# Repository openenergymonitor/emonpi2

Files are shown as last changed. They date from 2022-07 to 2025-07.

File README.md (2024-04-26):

# emonPi v2

The emonPi2 is an energy monitor that can monitor up to 6 AC circuits using CT sensors and the OpenEnergyMonitor emonVs voltage sensing unit. It consists of a measurement board that sits on top of a RaspberryPi. The measurement board features the Microchip AVR128DB348 microcontroller - responsible for sampling the current and voltage waveforms and calculating the power and energy values. The RaspberryPi provides full local data logging and visualisation capability. The emonPi2 can also be used as a basestation to receive data from other 433Mhz radio nodes.

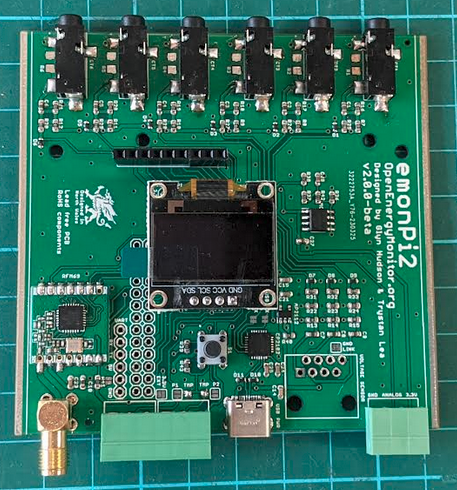
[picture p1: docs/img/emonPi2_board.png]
board


**Features**

- 6 CT sensor inputs (333mV voltage output CT's)
- RJ45: 1-3 phase voltage input
- Pulse and temperature sensing input
- Micro: AVR128DB48
- MCP1501 Precision reference
- RFM69CW radio
- USB-C
- I2C 128x64 SSD1306 Display
- RTC I2C Breakout
- Optional on-board UART

### [Hardware schematic and board files](hardware)

### [Firmware](firmware)

### Community & Support

- [OpenEnergyMonitor Forums](https://community.openenergymonitor.org)

OpenEnergyMonitor Shop Support: support@openenergymonitor.zendesk.com

### License

- The hardware designs (schematics and CAD files) are licensed under a Creative Commons Attribution-ShareAlike 3.0 Unported License.
- The firmware is released under the GNU GPL V3 license The documentation is subject to GNU Free Documentation License
- The hardware designs follow the terms of the OSHW (Open-source hardware) Statement of Principles 1.0.

### Disclaimer

```
OUR PRODUCTS AND ASSEMBLY KITS MAY BE USED BY EXPERIENCED, SKILLED USERS, AT THEIR OWN RISK. TO THE FULLEST EXTENT PERMISSIBLE BY THE APPLICABLE LAW, WE HEREBY DISCLAIM ANY AND ALL RESPONSIBILITY, RISK, LIABILITY AND DAMAGES ARISING OUT OF DEATH OR PERSONAL INJURY RESULTING FROM ASSEMBLY OR OPERATION OF OUR PRODUCTS.

Your safety is your own responsibility, including proper use of equipment and safety gear, and determining whether you have adequate skill and experience. OpenEnergyMonitor and Megni registered partnership disclaims all responsibility for any resulting damage, injury, or expense. It is your responsibility to make sure that your activities comply with applicable laws, including copyright. Always check the webpage associated with each unit before you get started. There may be important updates or corrections. All use of the instructions, kits, projects and suggestions given both by megni.co.uk, openenergymonitor.org and shop.openenergymonitor.org are to be used at your own risk. The technology (hardware , firmware and software) are constantly changing, documentation (including build guide and instructions) may not be complete or correct.

If you feel uncomfortable with assembling or using any part of the system, return it to us for a full refund.
```

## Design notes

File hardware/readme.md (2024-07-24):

# emonPi2 - Hardware

## Change Log 

### V2.0.0

First release 

### V2.0.1

**manufactured in April 2023**

- DFM tweaks 
- Fix pad sizes 
- Change USB-C connector footprint and enable duel orientation data connections 

The emonPi2 hardware schematics and board files have been developed using Eagle (now Autodesk). A free version is available to download here: https://www.autodesk.co.uk/products/eagle/free-download.

Alternatively it is also possible to open these board designs using KiKad which is open source.

**Schematic:**

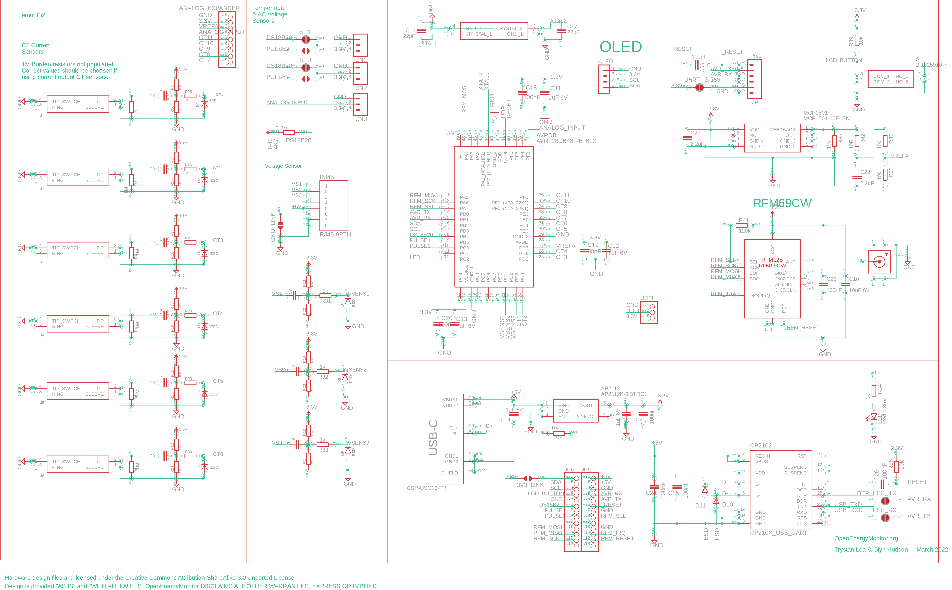
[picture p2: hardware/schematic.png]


**Board design:**

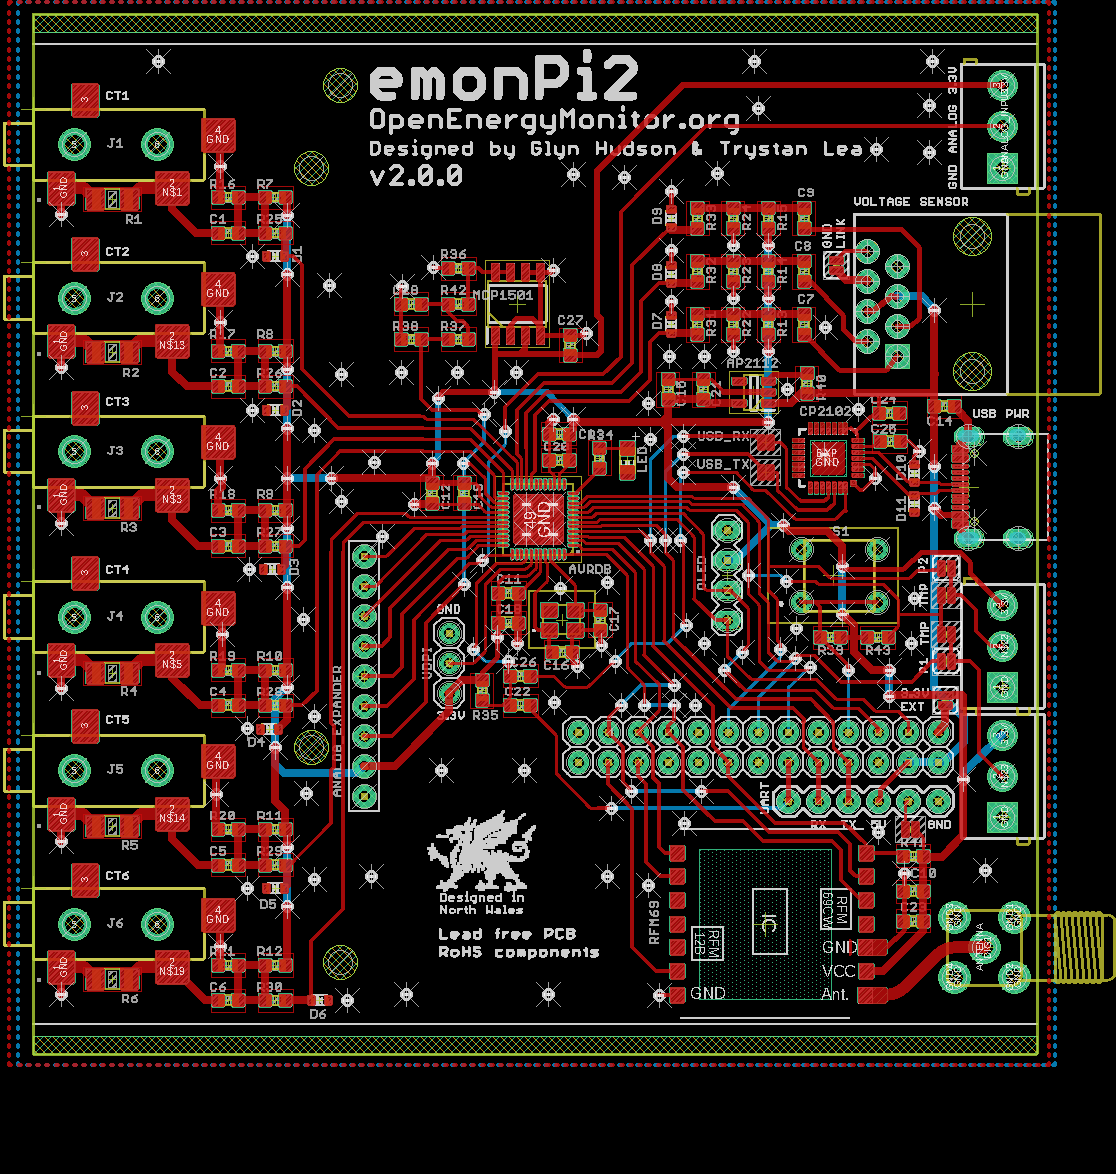
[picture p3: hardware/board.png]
board


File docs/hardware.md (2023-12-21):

---
github_url: "https://github.com/openenergymonitor/emontx4/blob/main/docs/hardware.md"
---

# Hardware

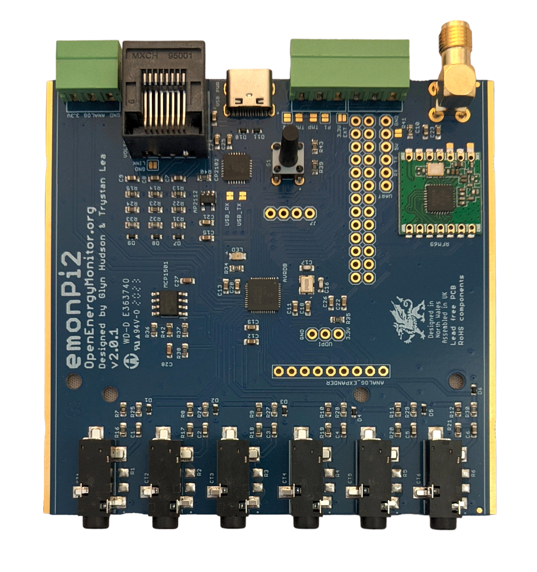
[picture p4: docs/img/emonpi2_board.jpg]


## Schematic

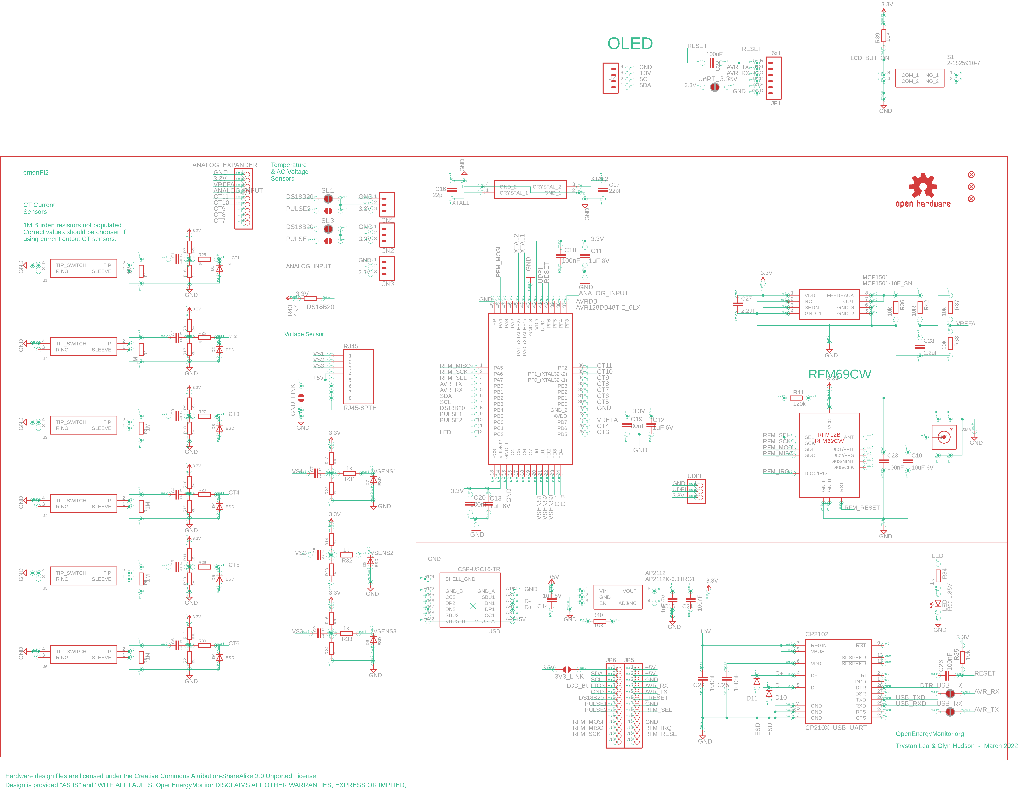
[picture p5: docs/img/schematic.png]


## Board layout

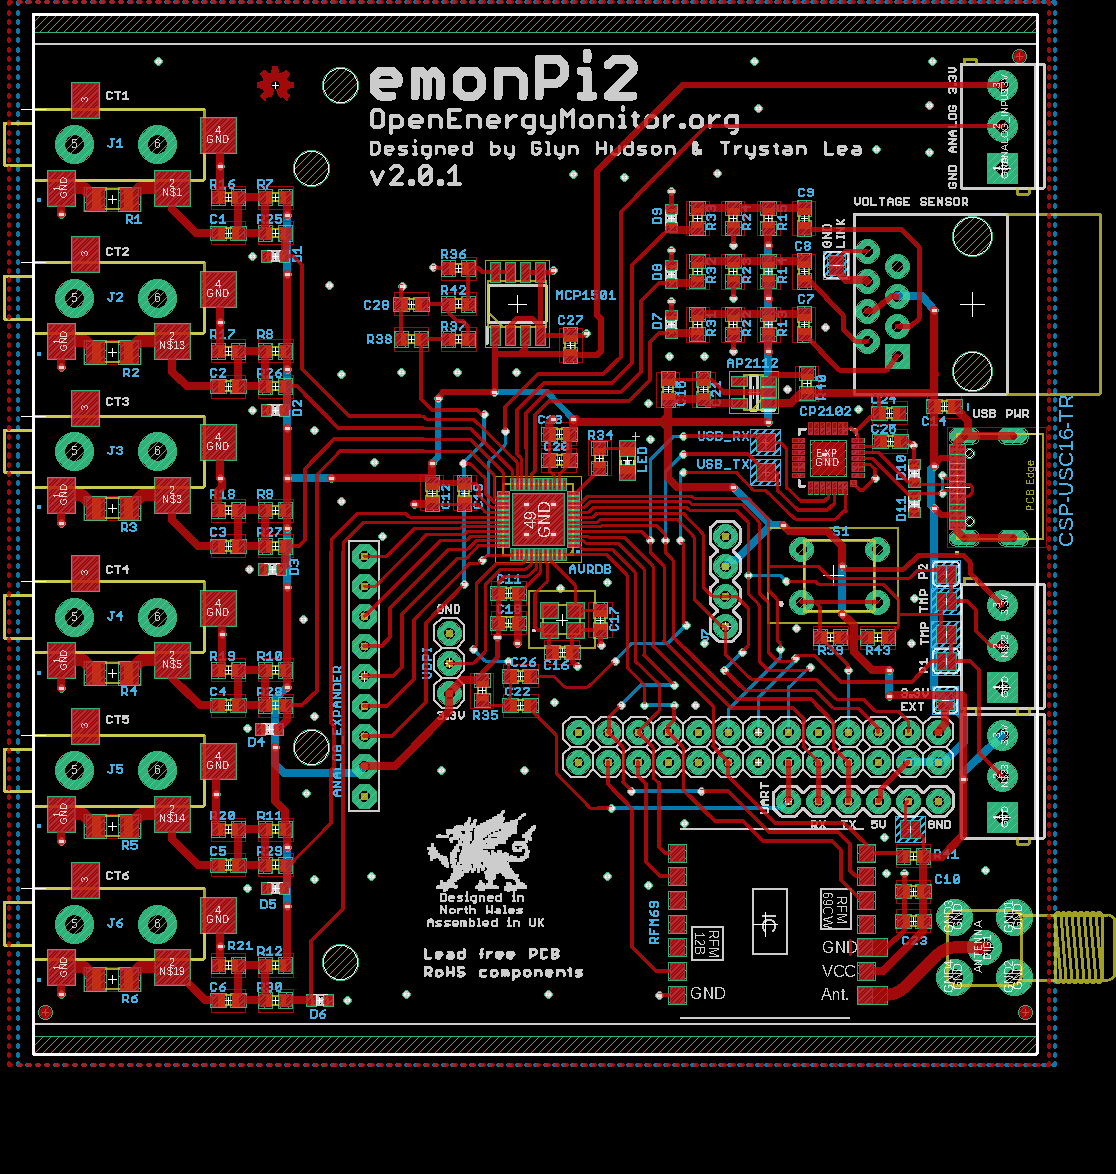
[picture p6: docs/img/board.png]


## Voltage sensor pinout

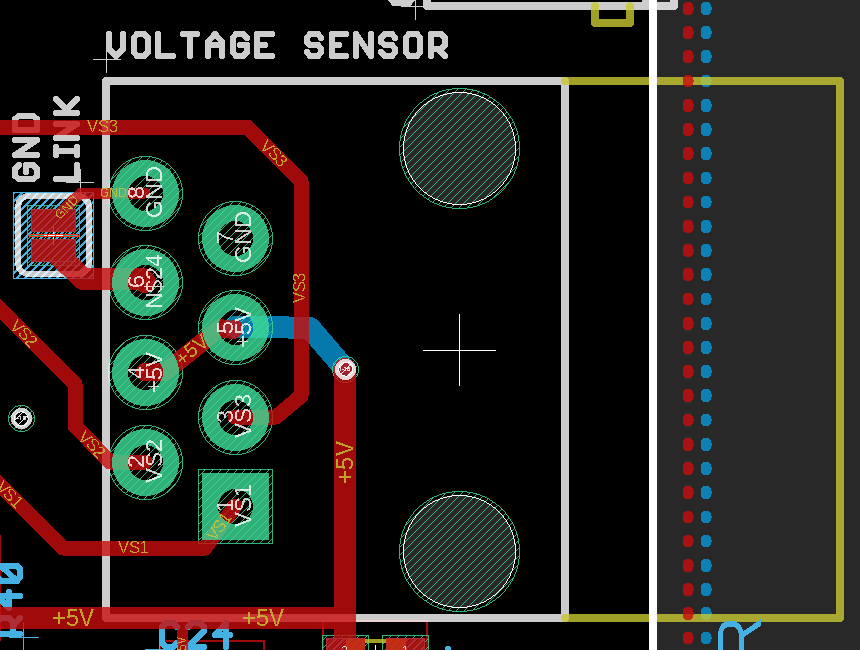
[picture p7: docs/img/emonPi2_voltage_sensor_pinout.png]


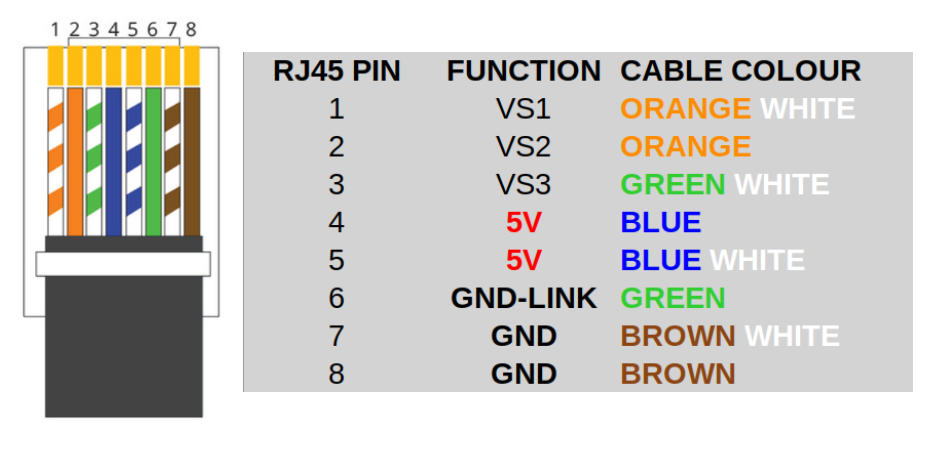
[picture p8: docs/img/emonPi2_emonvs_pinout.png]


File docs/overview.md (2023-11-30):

---
github_url: "https://github.com/openenergymonitor/emonpi2/blob/main/docs/overview.md"
---

# Overview

The emonPi2 builds directly on recent emonTx4 development, sharing a mostly identical PCB design. It provides the same 6x clip-on CT current sensor input functionality but with the RaspberryPi integrated in a single enclosure.

Like the emonTx4, the emonPi2 uses the same focus on higher accuracy, more CT channels, precision voltage sensing and the new microcontroller core. When combined with the emonVS voltage sensor and a selection of CT sensors, it provides an end-to-end electricity monitoring solution perfect for monitoring home consumption, solar generation, EV charging, heat pumps, battery storage among other applications.

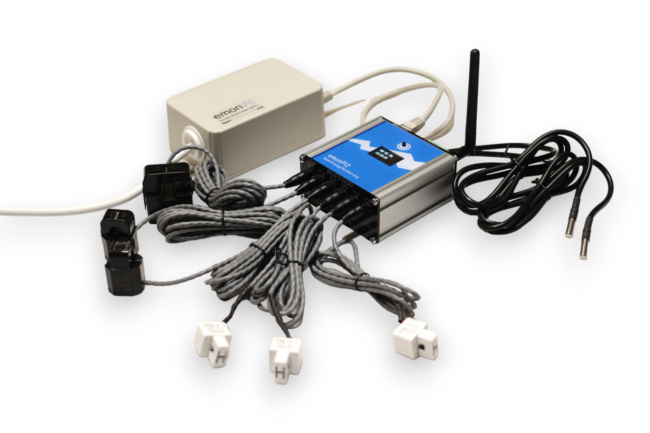
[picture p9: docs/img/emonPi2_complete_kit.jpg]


## Key features

- 6x clip-on CT current sensor inputs (suitable for a range of 333mV voltage output CT sensors).
- emonVs precision voltage sensor input.
- Full Real/Active power measurement & continuous sampling.
- Cumulative energy persisted on reboot.
- Both single and 3 phase support.
- 3 pluggable terminal block inputs for DS18B20 temperature sensing, pulse counting or an analogue voltage input.
- On-board USB to UART converter for easier programming and serial output.
- 433 MHz radio transceiver
- Standard RaspberryPi GPIO header connection for direct connection to a RaspberryPi
- Wall-mount aluminium enclosure

## Technical spec

- Microcontroller: [Microchip AVR128DB48](https://www.microchip.com/en-us/products/microcontrollers-and-microprocessors/8-bit-mcus/avr-mcus/avr-db)
- Arduino core support [DxCore by SpenceKonde](https://github.com/SpenceKonde/DxCore)
- ADC Resolution: 12-bit
- Precision voltage reference: [MCP1502](https://www.microchip.com/en-us/product/MCP1502)
- On board USB to UART converter: CP2102
- RFM69cw 433 MHz radio

## Accuracy

The emonPi2 includes the same accuracy improvements included in the emonTx4. The largest source of improvement comes from: a higher accuracy voltage sensor, higher accuracy CT current sensors and a wider range of CT sensors with current ratings that can better suit the load being monitored (making sure the analog-to-digital range of the microcontroller is being put to full use).

The key sensor and component tolerances are now:

- CT Sensors: ±0.5%
- EmonVs voltage sensor: ±0.5%
- Analog voltage reference ±0.2%
- Combined: ±1.2%

We have also upgraded the microcontroller from the ATmega328 to and AVR128DB48. The main improvement is a higher resolution ADC at 12-bits (4x the resolution of the ATmega328) alongside the capability to monitor more channels.

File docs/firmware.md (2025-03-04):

---
github_url: "https://github.com/openenergymonitor/emonpi2/blob/main/docs/firmware.md"
---

# Firmware

**Updated: 14th May 2024**<br>

There are currently 5 pre-compiled firmware options for the emonPi2 available via both the Emoncms firmware upload tool and the command line [emonupload.py](https://github.com/openenergymonitor/emonupload) firmware tool. 

**To choose the right firmware, there are 2 main questions:**

1. Is the application 1-phase, 3-phase (4-wire) or current only?<br>

2. Are you using a 6 channel expander for a total of 12 CT channels?<br>

*Note: Temperature sensing is handled by the RaspberryPi separately and so is not limited by firmware choice. The RFM69 radio transceiver is also handled by the RaspberryPi directly.*

Select the right firmware from the list that matches the requirements of your application:

| ID | Firmware | Voltage | CTs | Pulse|
| --- | --- | --- | --- | --- |
| 1 | emonPi2_DB_6CT_1phase | 1-ph | 6 | 1* |
| 2 | emonPi2_DB_6CT_3phase | 3-ph | 6 | 1* |
| 3 | emonPi2_DB_12CT_1phase | 1-ph | 12 | 3* |
| 4 | emonPi2_DB_12CT_3phase | 3-ph | 12 | 3* |
| 5 | emonPi2_CM_6CT | current only | 6 | 1 |

*The pulse sensor * denote standard firmware support for the number of pulse sensors given. Firmware modification can extend the number of pulse sensors to 3 on all emonLibDB based firmwares.*

- All firmwares include serial configuration of radio, voltage and current channel calibration values.

- **_DB:** EmonLib**DB** electricity monitoring library.<br>

- **_CM:**  EmonLib**CM** electricity monitoring library.

- **3-phase firmwares phase allocation:** follows the following pattern: 

  - CT1: phase 1
  - CT2: phase 2
  - CT3: phase 3
  - CT4: phase 1
  - CT5: phase 2
  - CT6: phase 3
  - continued for 12 CT expansion board...
  
- **3-phase (4-wire):** 3-phase support is for 3-phase, 4-wire systems only. That is systems with an L1, L2, L3 and a NEUTRAL wire. For 3-phase, 3-wire systems please contact us.

- **North American split-phase systems:** The 3-phase voltage sensor can also be used to provide voltage measurement for North American split-phase systems. A custom phase allocation will likely be required for this configuration which can be achieved by minor firmware modification.

- **Current only:** Supported by firmware 5 only, can be used with installations without an emonVs voltage sensor. These firmwares uses the older emonLibCM electricity monitoring library that has a fallback option to an assumed RMS voltage value if no AC voltage signal is detected.

- **Temperature sensing:** Is handled by the RaspberryPi separately via the emonHub software and so is not limited by firmware choice. While there is no specific limit on the number of temperature sensors that can be connected but we have only tested up to 6 temperature sensors at any one time.

- **Pulse sensing** is available on the 3 pin analog input terminal as default for all 6 CT firmwares but is disabled by default on the 12 CT firmwares as the analog input is used for CT 12. If temperature sensing is not required it is possible to configure pulse sensing on the terminal blocks connections typically used for temperature sensing.

- **Analog input:** Reading from the analog input can be enabled for all firmware variants via a `#define` compile option when compiling from source.

**Base firmwares**<br>
These are now built from a set of base firmware's common to all AVR-DB hardware variants (emonTx4, emonTx5 and emonPi2) available in the [avrdb_firmware repository](https://github.com/openenergymonitor/avrdb_firmware/)

- Firmwares 1 & 2 compiled from the `emon_DB_6CT` base firmware.
- Firmwares 3 & 4 are compiled from the `emon_DB_12CT` base firmware.
- Firmware 5 is compiled from the `emon_CM_6CT_temperature` base firmware.

---

## Updating firmware

The easiest way of updating the emonPi2 firmware is to use the firmware upload tool.

1. In your local emonPi2 web interface, navigate to: `Setup > Admin > Update > Firmware`.
2. Select serial port `ttyAMA0` and then select `emonPi2` from hardware.
3. Select firmware variant as required.



## Upload pre-compiled using EmonScripts emonupload2 tool 

On the emonPi/emonBase ensure EmonScripts is updated to latest version then run emonupload2 tool 

    cd /opt/openenergymonitor/EmonScripts
    ./emonupload2.py

Select hardware then firmware version

```
Select hardware:
  1. emonTx5
  2. emonPi2
  3. emonTx4
  4. emonPi
  5. emonTx3
  6. rfm69pi
  7. rfm12pi
  8. emonTH2
  9. JeeLink
Enter number:2

Select firmware:
1. emonPi2_DB_6CT_1phase                   2.1.0      (Standard LowPowerLabs)
2. emonPi2_DB_6CT_3phase                   2.1.0      (Standard LowPowerLabs)
3. emonPi2_DB_12CT_1phase                  1.2.0      (Standard LowPowerLabs)
4. emonPi2_DB_12CT_3phase                  1.2.0      (Standard LowPowerLabs)
5. emonPi2_CM_6CT                          1.6.0      (Standard LowPowerLabs)
Enter number:

```

emonupload2 tool can also be run on any other linux computer by cloning the EmonScripts repo then running the emonupload2.py python script. Python3 required 

    git clone https://github.com/openenergymonitor/EmonScripts

## Upload pre-compiled manually using avrdude

Alternatively to upload the same pre-compiled firmware via command line on emonPi / emonBase: 

    avrdude -C/opt/openenergymonitor/EmonScripts/update/avrdude.conf -v -pavr128db48 -carduino -D -P/dev/ttyUSB0 -b115200 -Uflash:w:emonPi2_DB_6CT_1phase_v2_1_0.ino.hex:i 

Or using different computer, ensure `avrdude.conf` has `avr128db48` entry i.e DxCore see below instructions 

    avrdude -Cavrdude.conf -v -pavr128db48 -carduino -D -P/dev/ttyUSB0 -b115200 -Uflash:w:emonPi2_DB_6CT_1phase_v2_1_0.ino.hex:i 
    
You will need avrdude installed (tested on version 6.3-2017) and the custom DxCore avrdude.conf. This can be downloaded here: [DxCore avrdude.conf](https://raw.githubusercontent.com/openenergymonitor/EmonScripts/master/update/avrdude.conf).

## How to compile and upload firmware

### Compile and Upload using PlatformIO (recommended)

Clone the `avrdb_firmware` repo 

    git clone https://github.com/openenergymonitor/avrdb_firmware
    cd avrdb_firmware/emon_DB_6CT
    
Open `emon_DB_6CT.ino` in an editor and change `#define EMONTX5` to `#define EMONPI2`. 

Change any other compile options as required e.g:

- to enable analog read uncomment `#define ENABLE_ANALOG`.
    
Install PlatformIO core then to compile and upload:

    pio run -t upload

On first run PlatformIO will download automatically all the required libraries. You can also use the PlatformIO GUI. 

### Compile and Upload using Arduino IDE 

If you don’t already have the Arduino IDE it can be downloaded from here:<br>
[https://www.arduino.cc/en/software](https://www.arduino.cc/en/software)

Once you have the IDE installed, you then need to install [Spence Konde’s DxCore](https://github.com/SpenceKonde/DxCore). This can be done by first pasting the following board manager URL in Arduino IDE > File > Preferences:

    http://drazzy.com/package_drazzy.com_index.json

Then navigating to: *Tools > Boards > Boards Manager*, Select “DxCore by Spence Konde” and click Install. 

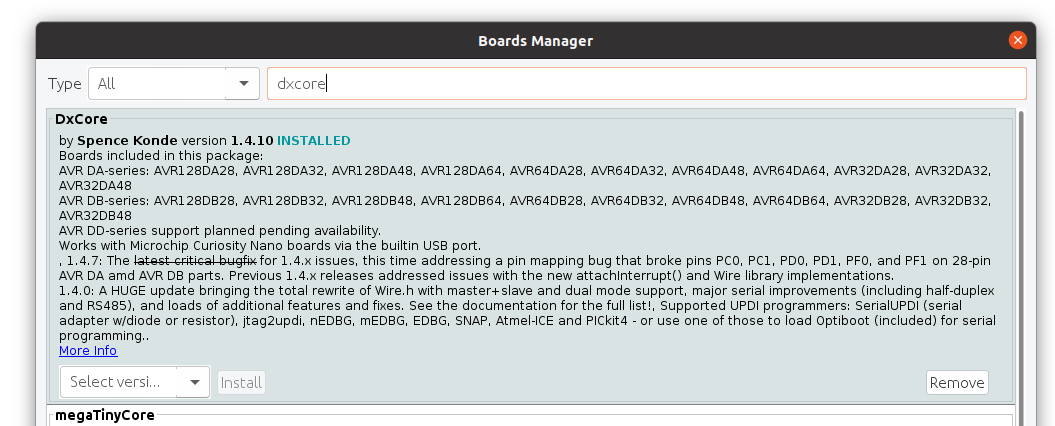
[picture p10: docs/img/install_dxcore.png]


For more information on DxCore installation see: [https://github.com/SpenceKonde/DxCore/blob/master/Installation.md](https://github.com/SpenceKonde/DxCore/blob/master/Installation.md).

**Libraries**

Locate or create your Arduino Sketchbook directory (location found in Arduino preferences). If it doesnt already exist, create a directory called libraries in the Sketchbook directory and install the following libraries:

1\. Download EmonLibCM library (avrdb branch)<br>
[https://github.com/openenergymonitor/EmonLibCM/tree/avrdb](https://github.com/openenergymonitor/EmonLibCM/tree/avrdb)

2\. Download EmonLibDB library (main branch)<br>
[https://github.com/openenergymonitor/emonLibDB](https://github.com/openenergymonitor/emonLibDB)

2\. Download emonEProm library (avrdb branch)<br>
[https://github.com/openenergymonitor/emonEProm/tree/avrdb](https://github.com/openenergymonitor/emonEProm/tree/avrdb)

3\. Download RFM69_LPL library (main branch)<br>
[https://github.com/openenergymonitor/RFM69_LPL](https://github.com/openenergymonitor/RFM69_LPL)

4\. Download RFM69_JeeLib library (avrdb branch)<br>
[https://github.com/openenergymonitor/RFM69_JeeLib/tree/avrdb](https://github.com/openenergymonitor/RFM69_JeeLib/tree/avrdb)

5\. Download DxCore SpenceKonde OneWire library:<br>
[https://github.com/SpenceKonde/OneWire](https://github.com/SpenceKonde/OneWire)

**Open and edit the AVR-DB firmware**

Clone the `avrdb_firmware` repo 

    git clone https://github.com/openenergymonitor/avrdb_firmware

Open the base firmware that you wish to use in the Arduino IDE e.g `emon_DB_6CT.ino`.

Change `#define EMONTX5` to `#define EMONPI2`. 

Change any other compile options as required e.g:

- to enable analog read uncomment `#define ENABLE_ANALOG`.

**Compilation settings:**

With DxCore and the libraries installed the firmware should then compile. 

Under Tools, select the following configuration options:

- Select Board "AVR DB-series (Optiboot)"
- Select Chip: AVR128DB48
- Clock Speed: 24 MHz Crystal
- Bootloader serial port: UART3: TXPB0, RXPB1

Select Board "AVR DB-series (Optiboot)"

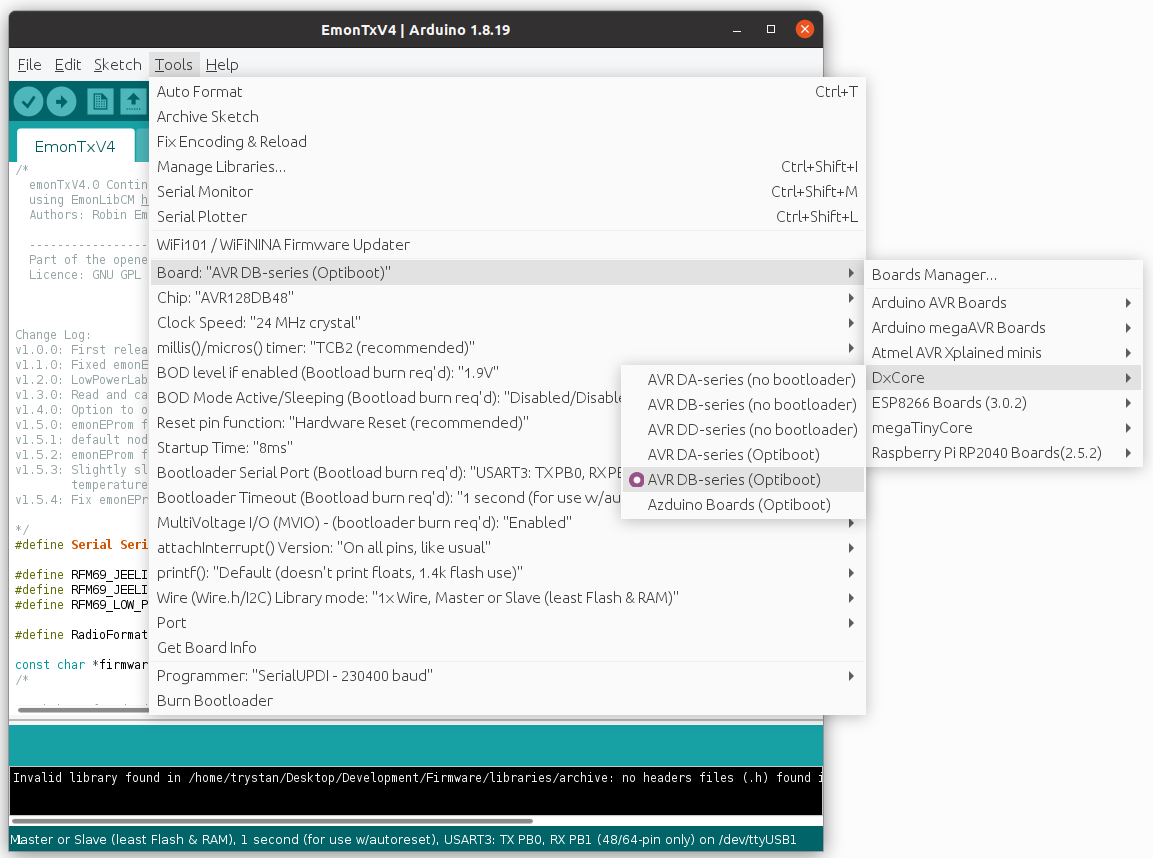
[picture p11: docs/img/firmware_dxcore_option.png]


Select Chip: AVR128DB48

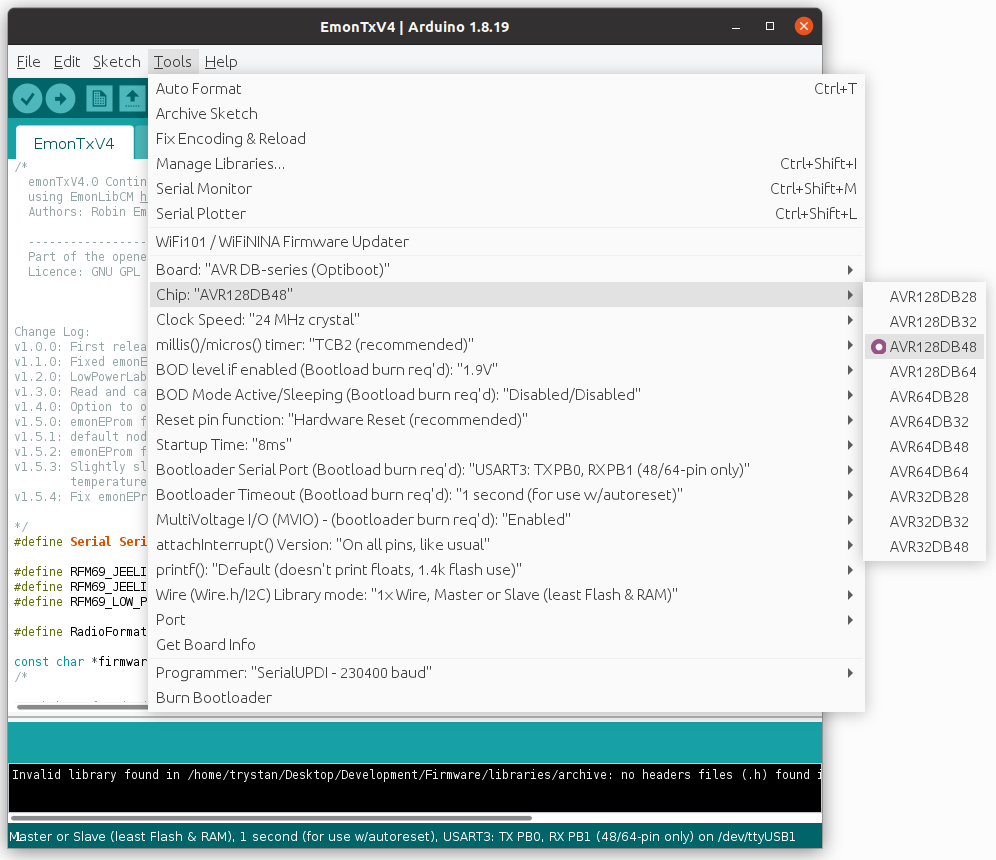
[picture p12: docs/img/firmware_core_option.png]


Bootloader serial port: UART3: TXPB0, RXPB1

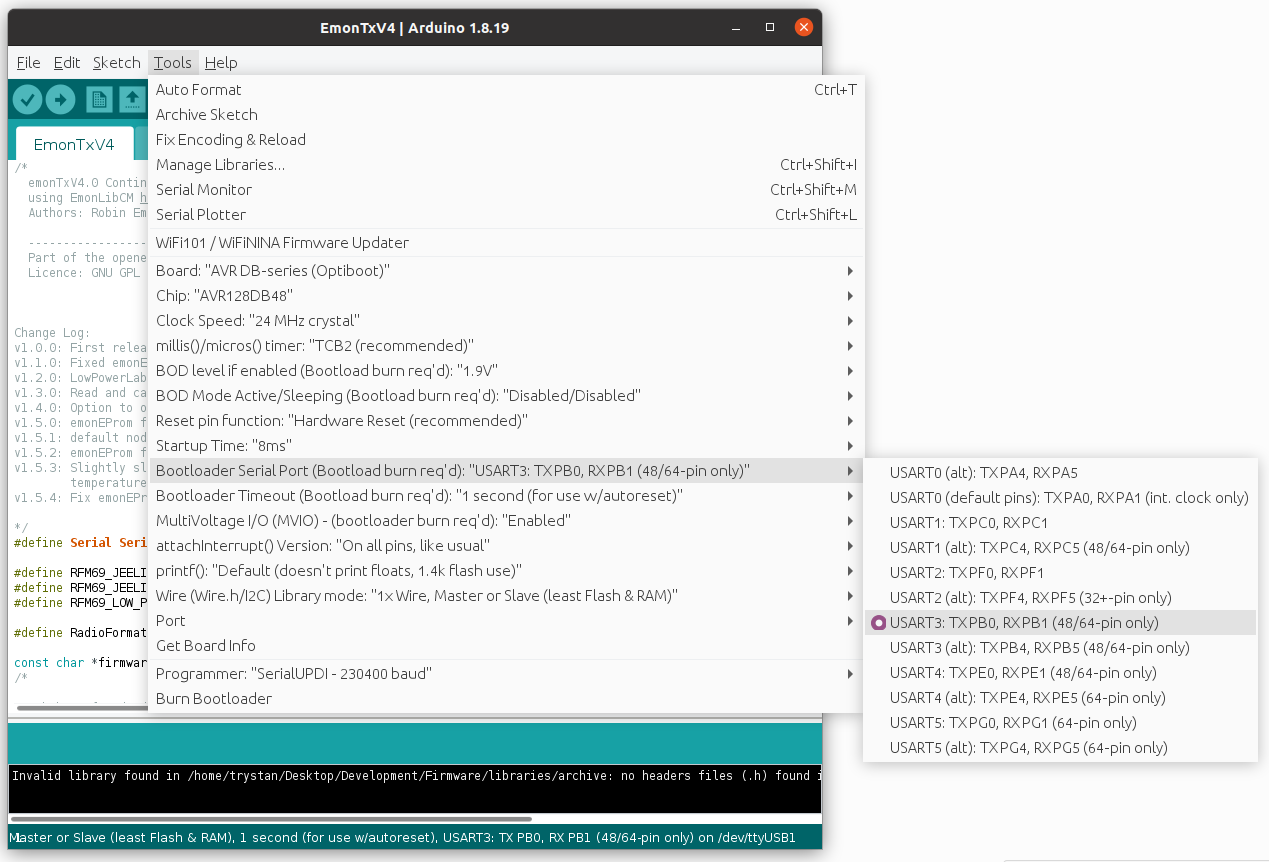
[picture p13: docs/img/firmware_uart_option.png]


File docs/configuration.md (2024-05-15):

---
github_url: "https://github.com/openenergymonitor/emonpi2/blob/main/docs/configuration.md"
---

# Configuration

CT calibration is usually pre-configured in the shop as part of the order process but can be re-configured at any point using the Serial Config tool available from the emonPi2 local Emoncms interface.

- Navigate to `Setup > Admin > Serial Config`
- Click on `Stop EmonHub` to temporarily stop the EmonHub service while we perform calibration.
- Select serial port `/dev/ttyAMA0` and click `Connect`.
- After a couple of seconds the emonPi2 will print out its current configuration which will populate the interface (if it does not do this type `l` and click `Send` to reload the calibration details from the emonPi2 measurement board).
- Adjust the  CT rating to match the CT sensor that you have installed on each channel.
- Click on `Save Changes` to ensure that the new configuration is recorded such that it persists when you power cycle the board.
- When finished, click on `Stop Serial` to disconnect the serial configuration tool and then `Start EmonHub` to restart the EmonHub service.

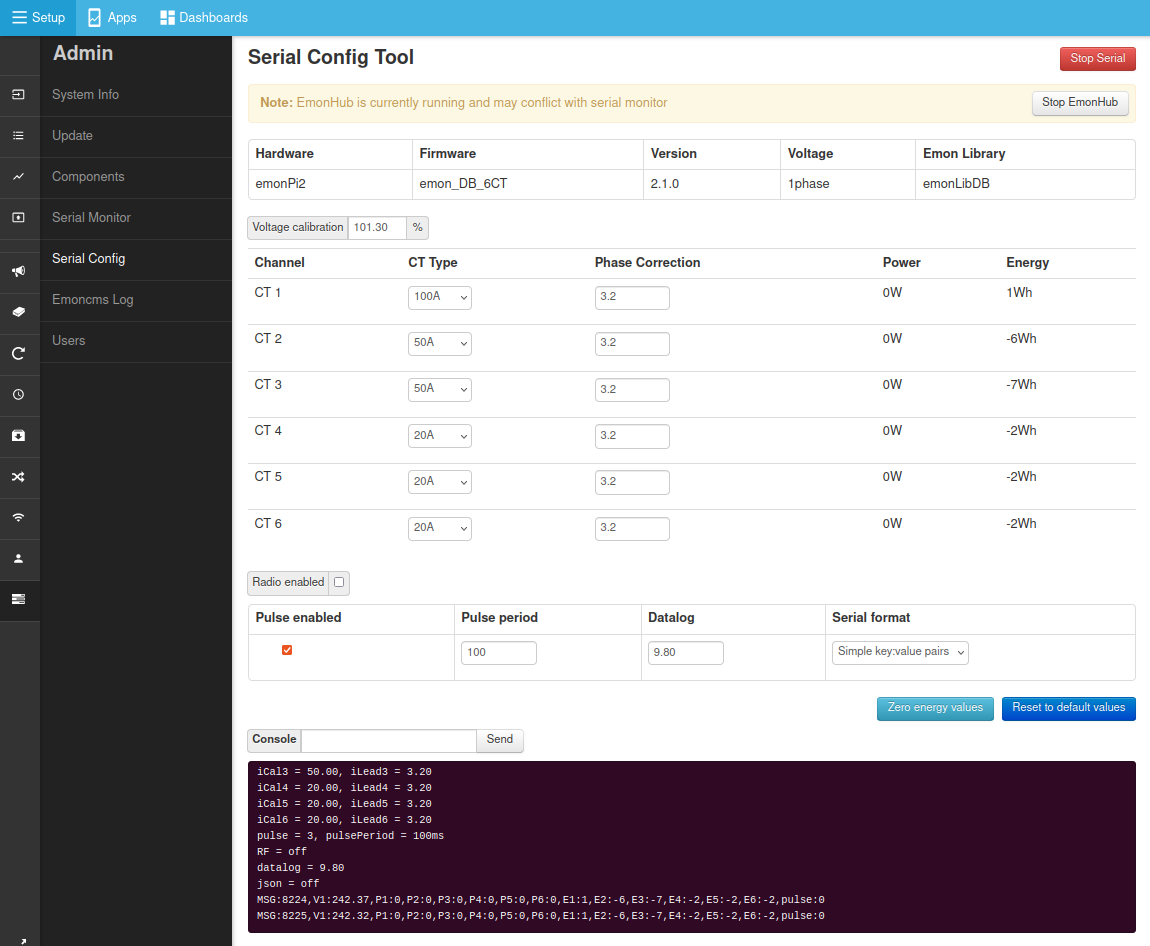
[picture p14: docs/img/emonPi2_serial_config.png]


## Directly via serial

Alternatively it's possible to configure the emonPi2 directly via serial using the arduino serial monitor or other similar tool. 
The following details the available commands and their function.

Available commands:

- **l** list the settings
- **r** restore sketch defaults
- **s** save settings to EEPROM
- **v** show firmware version
- **z** zero energy values
- **x** exit, lock and continue
- **?** show this text again
- **d\<xx.x\>** a floating point number for the datalogging period
- **c\<n\>** n = 0 for OFF, n = 1 for ON, enable current & power factor values to serial output for calibration.
- **f\<xx\>** the line frequency in Hz: normally either 50 or 60
- **k\<x\> \<yy.y\> \<zz.z\>**
  - Calibrate an analogue input channel:
  - x = a single numeral: 0 = voltage calibration, 1 = ct1 calibration, 2 = ct2 calibration, etc
  - yy.y = a floating point number for the voltage/current calibration constant
  - zz.z = a floating point number for the phase calibration for this c.t. (z is not needed, or ignored if supplied, when x = 0)
  - e.g. k0 101.3
  - k1 20.0 3.20
- **m\<x\> \<yy\>** meter pulse counting: 
  - x = 0 for OFF, x = 1 for ON
  - yy = an integer for the pulse minimum period in ms. (y is not needed, or ignored when x = 0)

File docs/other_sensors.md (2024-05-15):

---
github_url: "https://github.com/openenergymonitor/emontx4/blob/main/docs/other_sensors.md"
---

# Other sensors

## Temperature sensing

The emonPi2 supports temperature sensing via [DS18B20 temperature sensors](../electricity-monitoring/temperature/DS18B20-temperature-sensing.md). These are small temperature sensors with a 12-bit ADC and a digital output all in the sensor itself. Communication is over a one-wire bus and requires little in the way of additional components. The sensors have a quoted accuracy of ±0.5°C in the range -10°C to +85°C.

```{tip}
<b>Temperature sensing is handled by the RaspberryPi directly</b> rather than the measurement board microcontroller. This removes the hard limit on the number of temperature sensors that can be connected to the bus and allows sensor addresses to appear directly on the Emoncms inputs page. It also improves the accuracy of the electricity monitoring as the measurement board is freed up to focus soley on this task.

We have tested up to 6 temperature sensors connected at once, the one-wire bus should however support more than this. There is a useful discussion on how many sensors can be supported on a single RaspberryPi GPIO input [here](https://raspberrypi.stackexchange.com/questions/23701/what-is-the-maximum-number-of-ds18b20-probes-that-can-attached-to-one-input-port).
```

DS18B20 temperature sensors are connected via the labelled pluggable terminal blocks (multiple sensors can be connected to each temperature input, e.g using a 6x sensor breakout board). *Please note that temperature sensing is not broken out on the RJ45 connector which is for voltage sensing and power only.* 

**Pluggable terminal block connections are:**<br>
GND (black), DATA (yellow), 3.3V (red), left to right, repeated for each of the three blocks:

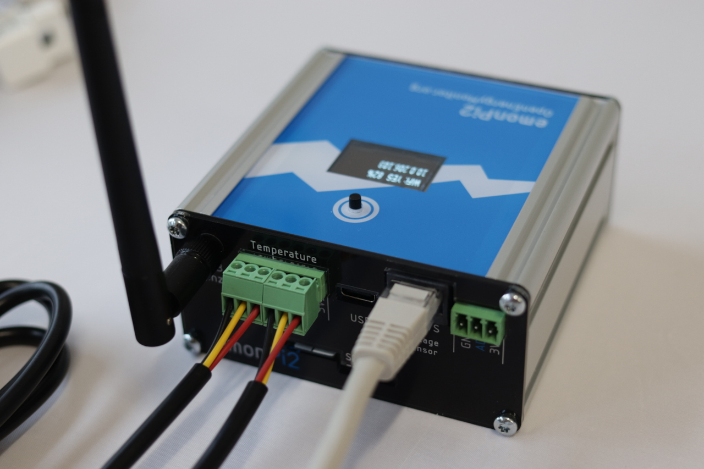
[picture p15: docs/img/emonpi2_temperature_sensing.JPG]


The function of the emonPi2 terminal blocks can be changed with small solder-jumpers just above the terminals on the measurement board PCB. The default configuration is 2x temperature sensor inputs, one on each terminal block. Notice the bridged solder jumpers labelled 'TMP' in the picture below: 

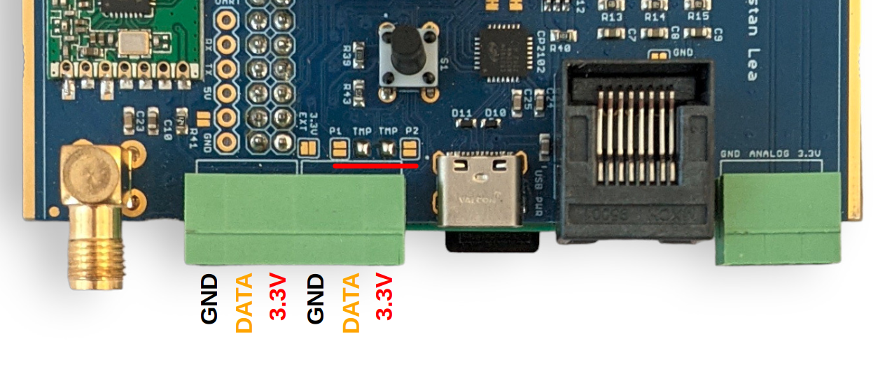
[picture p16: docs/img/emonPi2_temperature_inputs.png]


The DS18B20 input is connected to GPIO17 on the RaspberryPi via the GPIO connection header. *It is also connected to digital PIN_PB4 on the AVR128DB48 microcontroller for use in transmitter mode as part of an emonTx5.

## Pulse counting

**Update 14th May 2024:** When running the latest emonPi2 single phase or three phase firmware, pulse counting is attached to the analog input as standard which leaves the other terminals for easier connection of multiple temperature sensors.

The OpenEnergyMonitor pulse counter can connected like this:

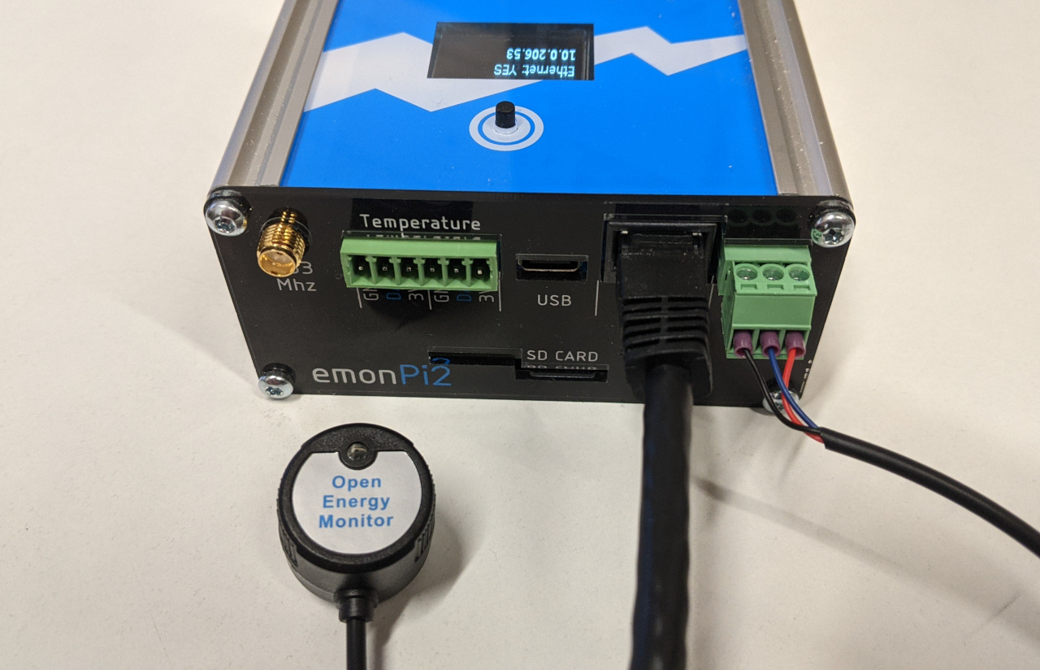
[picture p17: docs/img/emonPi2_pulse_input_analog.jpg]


This pulse input will appear alongside the energy monitoring data from the emonPi2 on the emoncms inputs page. Note that the voltage sensor is required for this firmware to work.

---

**Pulse sensing using the terminals labelled 'temperature'**:

While the left hand side terminal block inputs are configured for temperature sensing as standard, it's possible to change the function of the 'Data' pin on each of the terminal block inputs. The following picture shows both inputs configured for pulse counting rather than temperature sensing, notice the moved solder pad bridges:

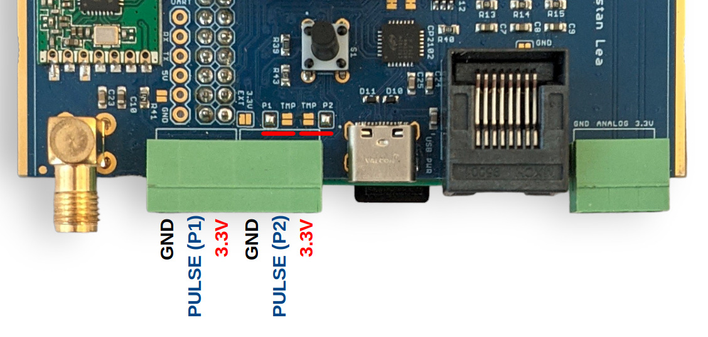
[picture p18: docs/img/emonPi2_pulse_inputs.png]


```{note}
<b>T1</b> can be either a pulse input (<b>Pi GPIO27 PIN13</b> or AVR-DB PIN_PB5) or temperature sensing (<b>Pi GPIO17</b> or AVR-DB PIN_PB4)

<b>T2</b> can be either a pulse input (<b>Pi GPIO22 pin-15</b> or AVR-DB PIN_PC0) or temperature sensing (<b>Pi GPIO17</b> or AVR-DB PIN_PB4)
```

It is easy to increase the number of pulse inputs when temperature sensing is not required. Simply select the P1 and P2 solder bridges above and add the following emonhub.conf interfacer configuration. This will enable direct readings from the applicable pulse inputs on the Pi, bypassing the AVR-DB microcontroller:

```
[[pulse1]]
    Type = EmonHubPulseCounterInterfacer
    [[[init_settings]]]
        pulse_pin = 13
        # bouncetime = 2
        # rate_limit = 2
    [[[runtimesettings]]]
        pubchannels = ToEmonCMS,
        nodeoffset = 1

[[pulse2]]
    Type = EmonHubPulseCounterInterfacer
    [[[init_settings]]]
        pulse_pin = 15
        # bouncetime = 2
        # rate_limit = 2
    [[[runtimesettings]]]
        pubchannels = ToEmonCMS,
        nodeoffset = 2
```

On pulse detection, the pulse inputs will appear on the Emoncms inputs page:

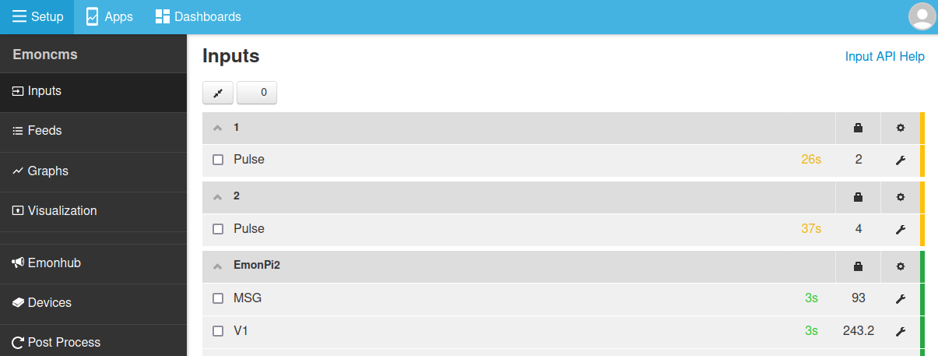
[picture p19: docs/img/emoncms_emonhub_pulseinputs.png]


---

## Analog input

It's possible to link analog input AIN19 (CT12) to right-most terminal block as shown here. An example application is measuring flow rate using a Sika VFS which has an analog voltage output.

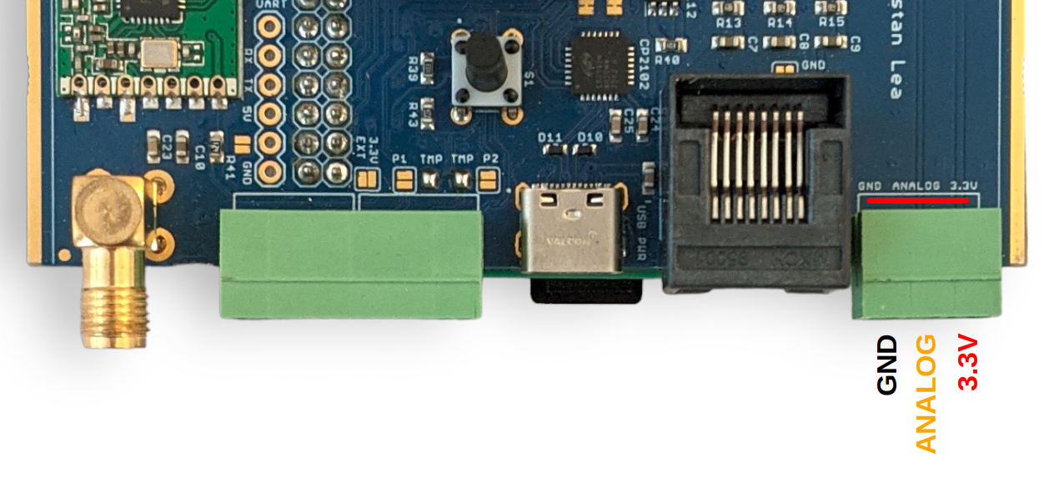
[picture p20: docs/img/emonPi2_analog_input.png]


```{warning}
The analog input voltage must be in the range **0 - 1.024V**. This ADC is configured for this range in order to suit the 333mV CT sensors. This analog input can not be used when using the emonPi2 with the C.T Extender board.
```

Using the analog input requires compiling and uploading custom configuration of the emonPi2 firmware. Start by setting up the Arduino IDE environment following the [firmware guide](firmware.md).

Open the base firmware `emon_DB_6CT` from the [avrdb_firmware](https://github.com/openenergymonitor/avrdb_firmware) firmware repository.

1\. Make sure to select EMONPI2 as the hardware variant:

```
// 1. Set hardware variant
// Options: EMONTX4, EMONTX5, EMONPI2
#define EMONPI2
```

2\. Uncomment the line `#define ENABLE_ANALOG`:

```
// 6. Enable analog reading (disabled by default)
// #define ENABLE_ANALOG
```

3\. Select 1phase or 3phase as required:

```
// 3. Set number of voltage channels (1 for single phase, 3 for three phase)
#define NUM_V_CHANNELS 1
```

4\. Compile and upload the firmware to the emonPi2

With this firmware loaded the analog input will appear in the input list.

The following set of screenshots gives an example of configuring this analog input for use in reading the flow rate from a Sika VFS flow sensor. The flow rate is then used together with measurement of flow and return temperature to calculate heat.

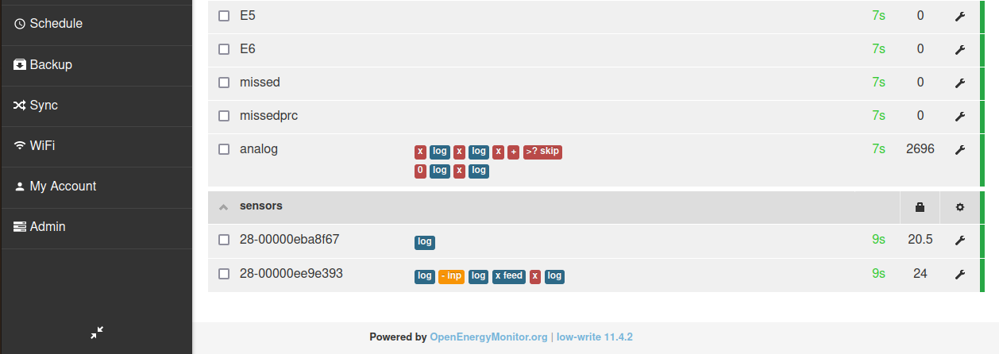
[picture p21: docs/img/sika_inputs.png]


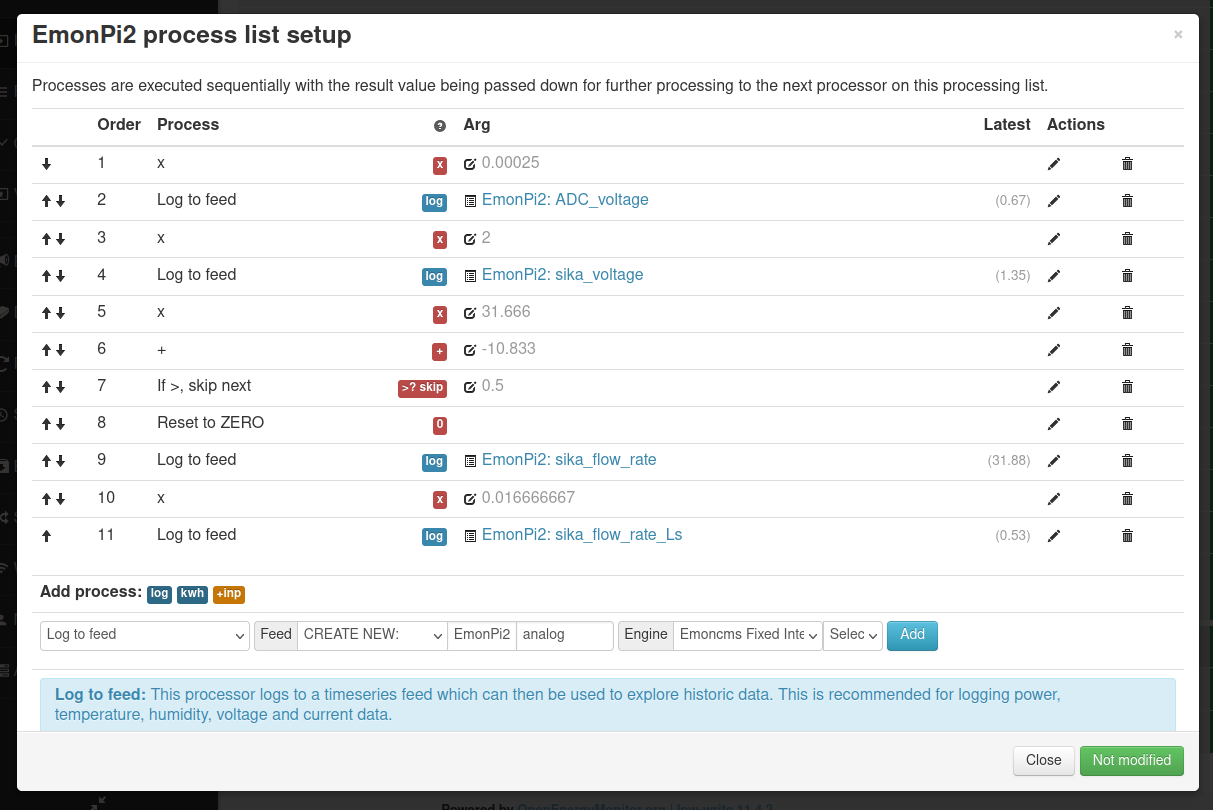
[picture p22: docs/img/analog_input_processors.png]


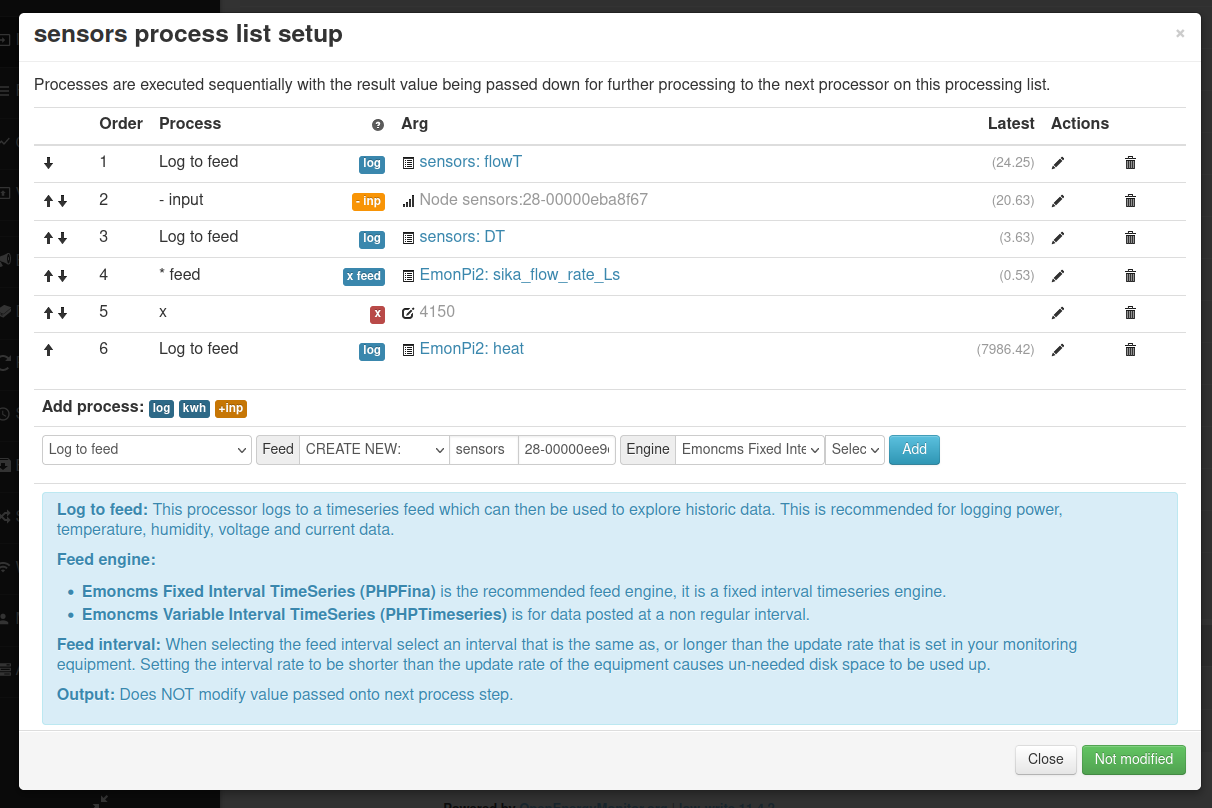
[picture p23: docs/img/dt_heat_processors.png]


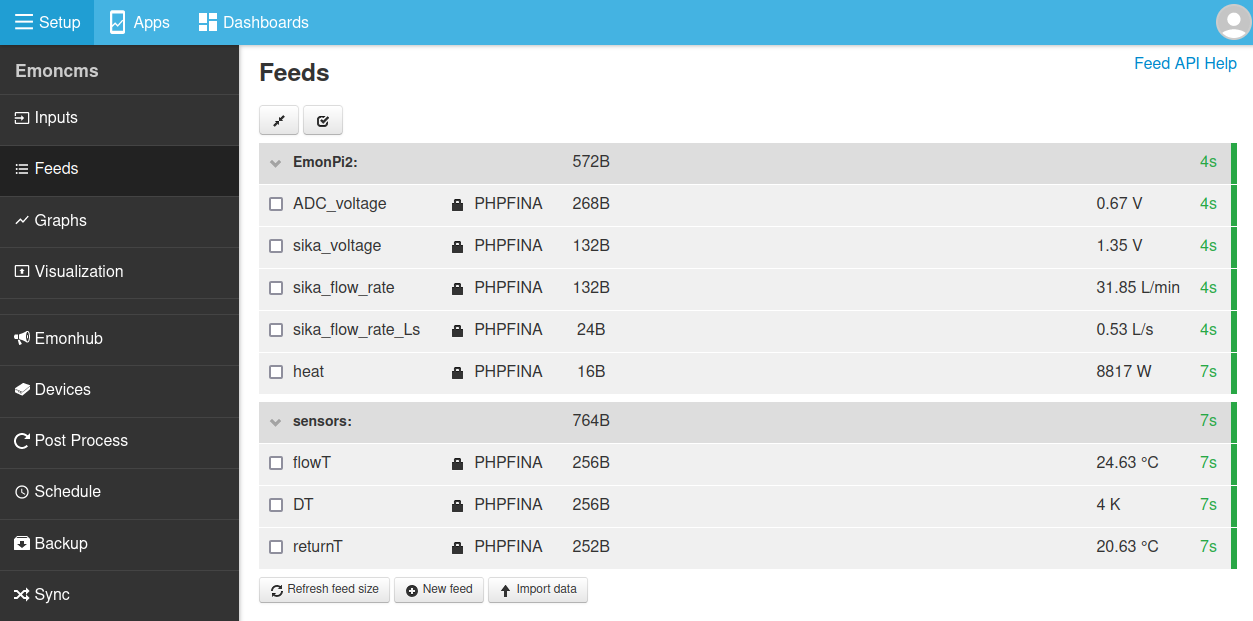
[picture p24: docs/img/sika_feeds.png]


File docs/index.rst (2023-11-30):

emonPi2 User Guide
==================

.. toctree::
   :maxdepth: 2
   
   overview.md
   Install Guide <install.md>
   configuration.md
   firmware.md
   hardware.md
   Temperature, Pulse & Analog <other_sensors.md>

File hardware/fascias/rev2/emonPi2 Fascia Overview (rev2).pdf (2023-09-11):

Back (92mm x 45mm)

Bottom Plate
(74mm x 85mm)

Material: Clear acrylic 2mm Red = No screen print (clear) Gray = Cut-out (hole)
White / blue = screen print

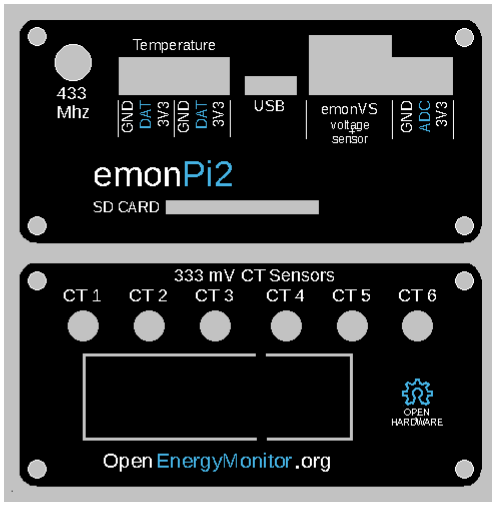
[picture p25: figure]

OpenEnergyMonitor emonPi2 rev 2 | U-Case 1 extrusion - x 85mm long (quote:130895)

Material: Black 2mm acrylic Gray = Cut-out
White / blue = screen print

Front (92mm x 45mm) Top plate (74mm x 85mm)

Material: aluminium plate
(gray) 1.9mm
TOP | FASCIAS | BOTTOM

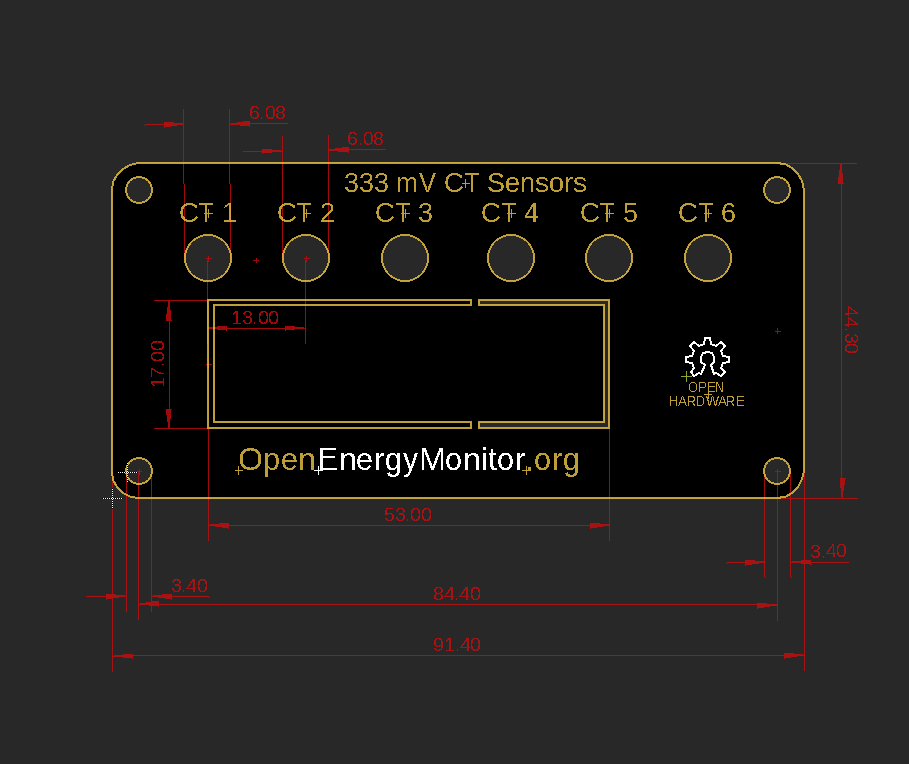
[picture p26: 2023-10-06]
hardware/fascias/rev2/dxf - emonPi2 rev3/front-dimentions.png

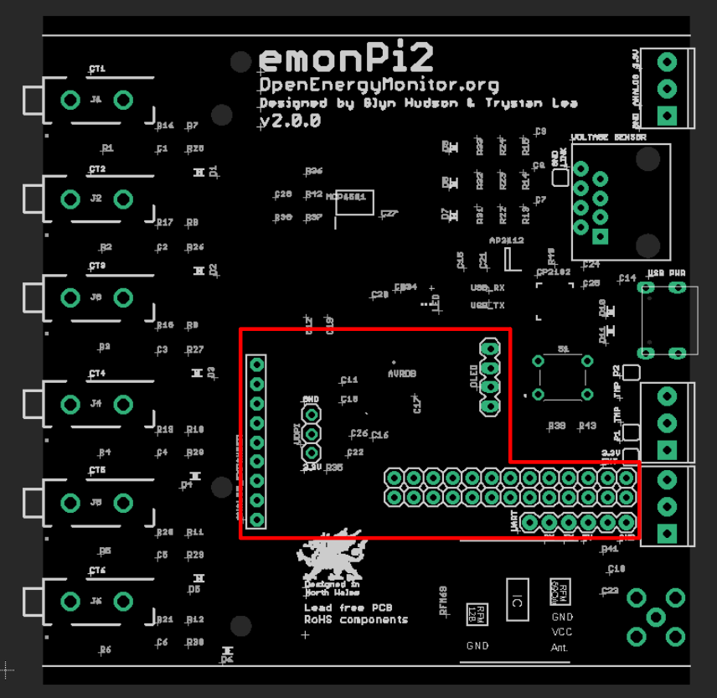
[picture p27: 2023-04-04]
hardware/hole_masking.png

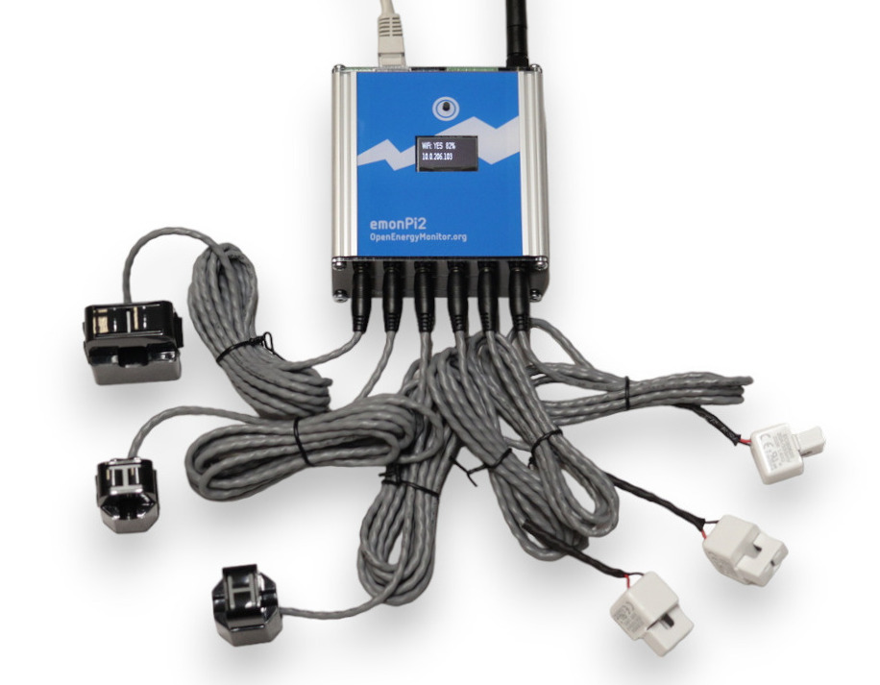
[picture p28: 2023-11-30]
docs/img/emonPi2_CTs2.jpg

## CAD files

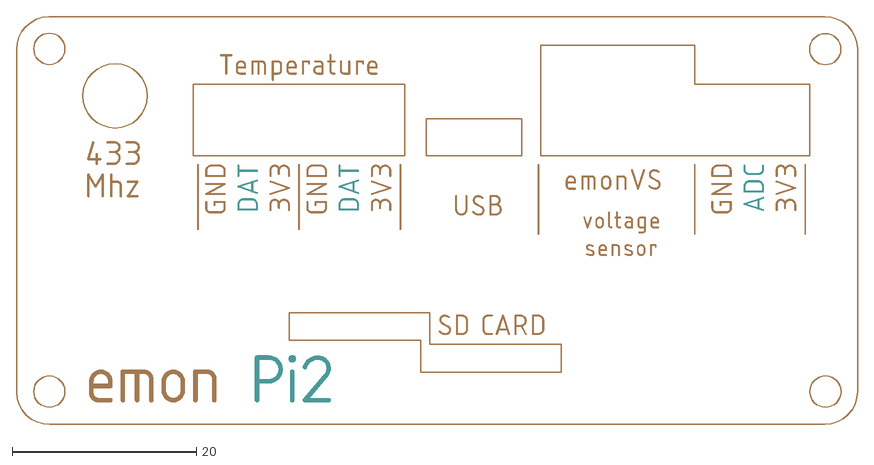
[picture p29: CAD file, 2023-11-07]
hardware/fascias/rev2/dxf - emonPi2 rev3/back.dxf
91.4 x 44.4

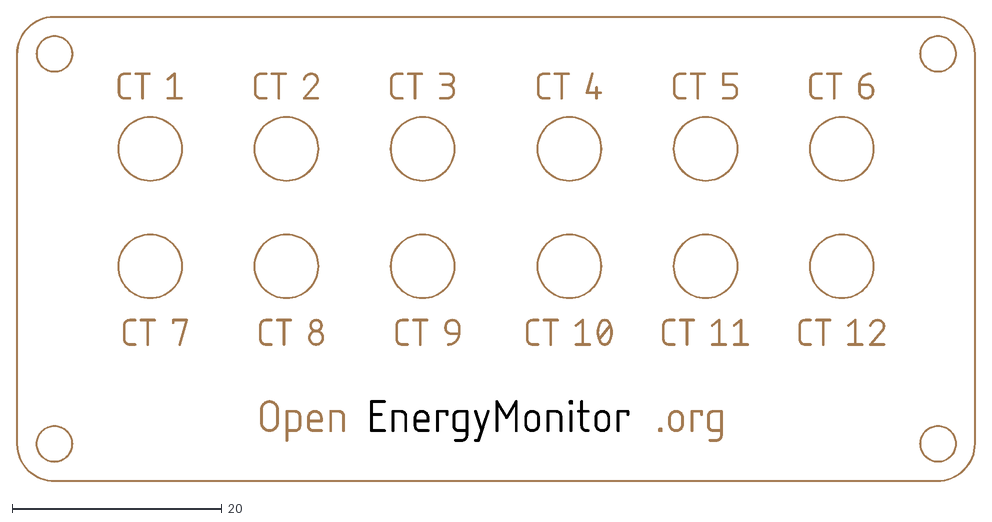
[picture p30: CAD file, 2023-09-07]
hardware/fascias/rev2/frontB.dxf
91.5 x 44.5

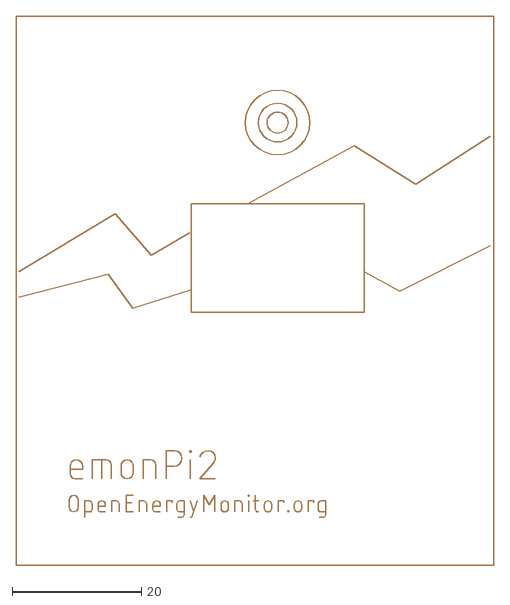
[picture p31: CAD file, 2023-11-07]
hardware/fascias/rev2/dxf - emonPi2 rev3/top.dxf
74.0 x 85.0

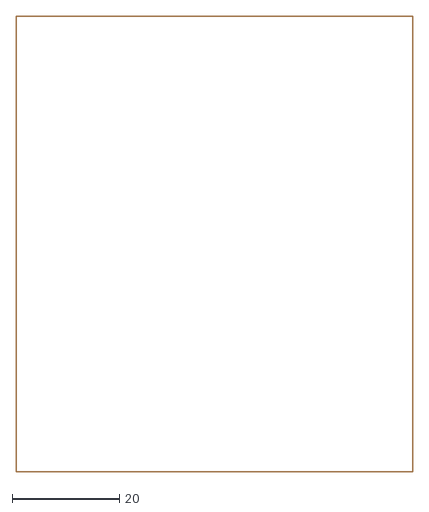
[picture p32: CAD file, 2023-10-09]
hardware/fascias/rev2/dxf - emonPi2 rev3/bottom.dxf
74.0 x 85.0

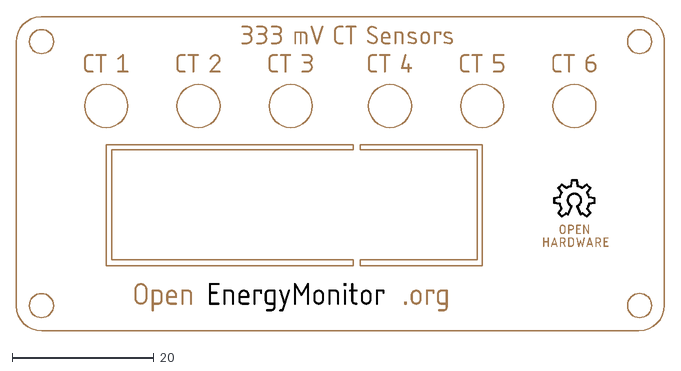
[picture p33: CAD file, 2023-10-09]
hardware/fascias/rev2/dxf - emonPi2 rev3/front.dxf
91.5 x 44.4

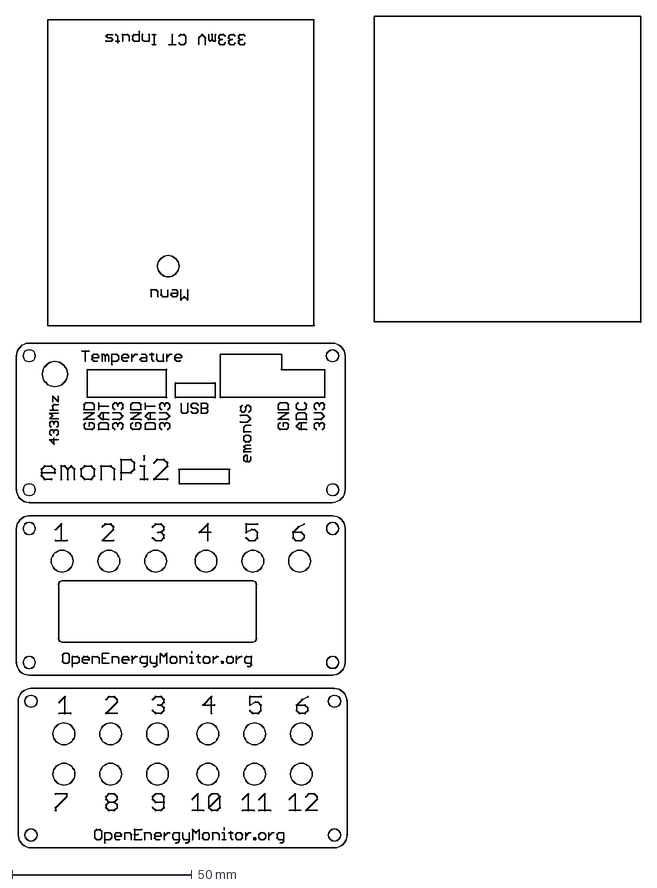
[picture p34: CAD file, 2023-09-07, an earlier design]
hardware/fascias/rev1/#fascias_v2.0.0-2mm.dxf
173.6 x 231.3 mm

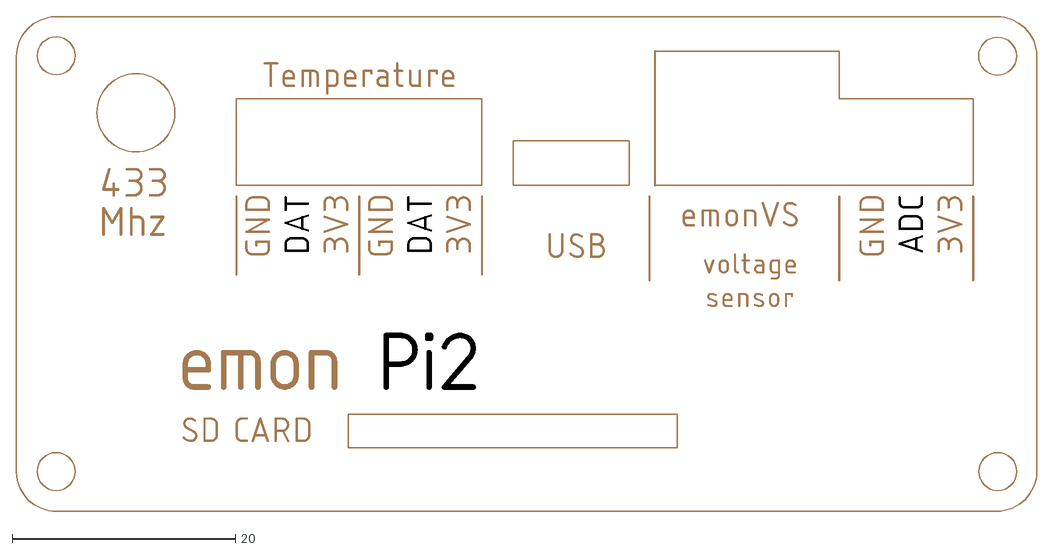
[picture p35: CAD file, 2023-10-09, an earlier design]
hardware/fascias/rev2/dxf - emonPi2 rev2/back.dxf
91.4 x 44.4

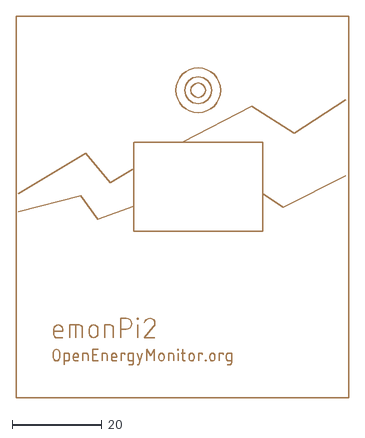
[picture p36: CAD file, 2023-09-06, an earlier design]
hardware/fascias/rev2/dxf - emonPi2 rev2/top.dxf
74.0 x 85.0

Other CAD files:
hardware/fascias/rev1/fascias_v2.0.0-2mm.dxf

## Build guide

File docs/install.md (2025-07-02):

---
github_url: "https://github.com/openenergymonitor/emonpi2/blob/main/docs/install.md"
---

# emonPi2 Install Guide

The following guide covers installation of the [emonPi2 6x input energy monitor and integrated base-station](overview.md).

<iframe width="560" height="315" src="https://www.youtube.com/embed/XAJV5zDJF_4?si=5aG4XxaeXYWK0_xQ" title="YouTube video player" frameborder="0" allow="accelerometer; autoplay; clipboard-write; encrypted-media; gyroscope; picture-in-picture; web-share" referrerpolicy="strict-origin-when-cross-origin" allowfullscreen></iframe>

**Hardware covered in this guide:**

- [emonPi2: 6 input energy monitor](overview.md)
- [emonVs: Precision voltage sensor and power supply](voltage_sensors.md)
- Up to 6 CT sensors
- RJ45 voltage sensor and power supply cable

## Quick Start

1. Clip the CT current sensors around Live OR Neutral cable of the AC circuit to be measured (not both), note CT direction K -> L (L: Load), That’s on the Line conductor, the arrow points
away from the load on the Neutral.

2. Plug the CT current sensors into emonPi2 via 3.5mm jack plugs

3. Plug emonVs RJ45 cable into emonPi2

4. Plug emonVs into mains power via a domestic wall socket

5. (optionally) If you have the RaspberryPi 4 variant of the emonPi2 a hard wired Ethernet internet/LAN connection can be connected.

6. Switch on mains socket. The display on the emonPi2 will show `emonPi2, starting..`. On the SD card side of the case the RaspberryPi 4 indicator LED should be visible through the black face plate.

7. If using Ethernet, continue with [step 5. Connecting via Ethernet](#connecting-via-ethernet). If using WiFi, continue with [step 6. Connecting via WiFi](#connecting-via-wifi).

```{admonition} Instructions for safe use
- Clip-on CT sensors are non-invasive and should not have direct contact with the AC mains. As a precaution, we recommend ensuring all cables are fully isolated prior to installing. If in doubt seek professional assistance.
- Do not expose to water or moisture
- Do not expose to temperate above rated operating limits
- Indoor use only
- Do not connect unapproved accessories
- Please contact us if you have any questions
```



---

## Extended version

A good place to start is to assess the location where you wish to install the emonPi2, identify the circuits that you wish to monitor using the clip-on CT sensors and decide how you would like to install the emonVs voltage sensor. There are a couple of example installations given below which may provide inspiration.

## 1. emonVs installation

There are two different ways of installing the [emonVs voltage sensor](https://shop.openenergymonitor.com/power-supplies/):

**Using the mains plug supplied:** If you have a convenient socket near-by this will be the easiest and quickest option.<br>

**Direct installation:** The emonVs can be hardwired by a suitably competent person into a 6A or lower circuit protection device in the fuse board (consumer unit) or a 3A fused spur. The supplied emonVs mains power cable has a cross sectional area of 1.0mm<sup>2</sup>. This can provide a tidy installation if no socket is available and helps ensure higher monitoring uptime if sockets are at risk of being unplugged for use by other appliances.

The emonVs unit can be wall mounted using the brackets on the enclosure.

If in North America, you likely want the [3-phase version of the emonVS](https://shop.openenergymonitor.com/emonvs-3-phase-no-plug/), as this will allow you to use the split phase [firmware](firmware.md). The split phase firmware enables the most accurate power measurements.

If you plan on using an [emonTx5 with your emonPi2](../emontx5/install.md), you will likely want an [emonVs RJ45 duplicator](https://shop.openenergymonitor.com/emonvs-rj45-duplicator/) to use a single emonVs with both devices.

## 2. CT sensor installation

- Current transformers (CTs) are sensors that measure alternating current (AC).

- The emonPi2 supports a wide variety of 333mV voltage output CT sensors. We stock 20A, 50A, 100A & 200A options in the OpenEnergyMonitor shop. The physical size of these CT sensors is also roughly proportional to their current rating. For highest accuracy it's a good idea to choose CT sensors that match the rating of the circuit being monitored. As an example a 20A CT should be used for 16A or 20A circuits, a 50A CT for 32A EV chargers or 100A CT for whole house monitoring (assuming a 100A rated supply).

- CT sensors need to be clipped around the Live OR Neutral cable of the AC circuit to be measured (not both). The CT sensors have an indicated direction printed on the case `K->L`, where L is the direction of the load. That’s on the Line conductor, the arrow points away from the load on the Neutral. This will ensure the correct sign (+/-) on the power readings.

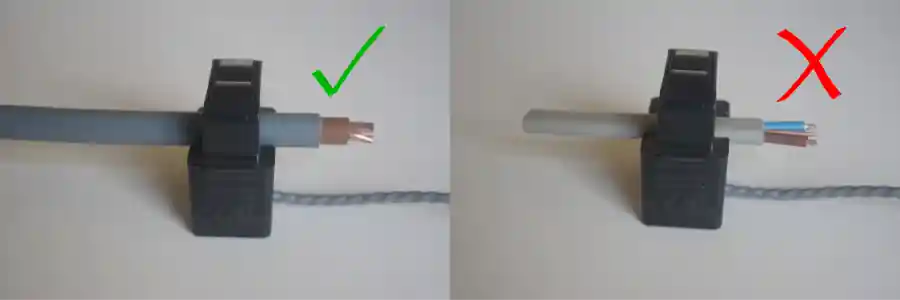
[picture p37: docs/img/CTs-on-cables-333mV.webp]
CTs on cables
  

- Take care not to compress the sensor with any sideways force as this can affect the accuracy of the measurement.

- The new range of CT sensors used with the emonPi2 are all voltage output CT sensors with integrated burden resistors and so are safe to clip on to the circuits that you wish to measure before plugging into the emonPi2 if that makes installation easier.

- Note the CT sensor used on each circuit, as well as the channel number on the emonPi2 that the CT is connected to, as this may be required to calibrate the emonPi2 if you are using non standard CT ratings. It's worth making a physical note of this on a label next to the emonPi2 for future reference.

```{note}
The emonPi2 requires voltage output CT sensors, it is not compatible with the old current output YHDC (blue) 100A CT sensors - unless appropriate burden resistors are installed.
```

```{tip} 
With 6 CT sensor cables and often more cable than you need, it's easy for an installation to look like a hive of wires! A little electrical trunking can go a long way to tidying it all up, allowing for excess cable to be looped back on itself.
```

## 3. emonPi2 Installation

- The emonPi2 can be wall mounted using the wall mounting kit supplied. Installation on it's side, with the aluminium side plates on the top and bottom can help reduce risk of things falling onto the sockets and can make for an easier installation in terms of CT sensor routing.

- Plug in the CT sensors, note which CT sensor is plugged into each input on the emonPi2 as each input needs to have the correct calibration applied.

- Connect the RJ45 cable (ethernet sized connector with 8 pins) from the emonVs voltage sensor and power supply to the RJ45 socket on the opposite side of the case to the CT sensor sockets. (If you have the RaspberryPi 4 variant of the emonPi2 the RaspberryPi Ethernet socket is on the same side as the CT sensors, avoid plugging the emonVs RJ45 cable into the Ethernet socket and vice versa).

## 4. Startup and display menu

With the emonPi2 powered up a simple `emonPi2 starting...` message will be printed on the display. The RaspberryPi is booting at this point which usually takes around 40 seconds: 

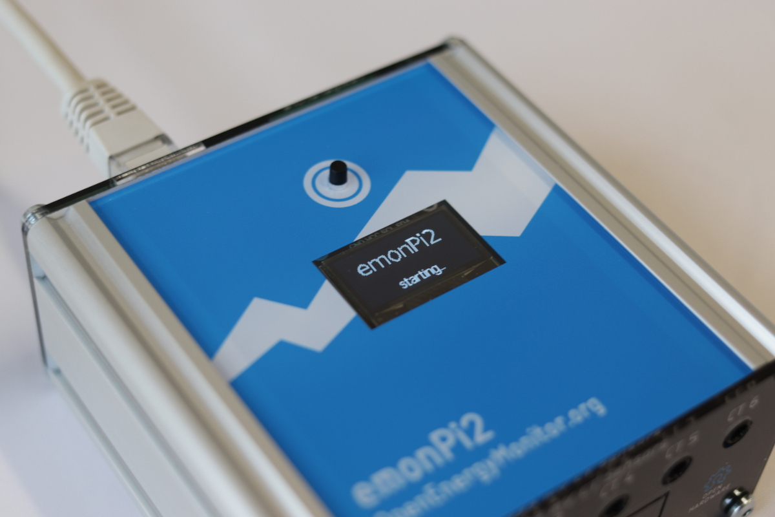
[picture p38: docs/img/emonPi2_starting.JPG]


Once booted the display will print the SD card image version and emonPi2 serial number: 

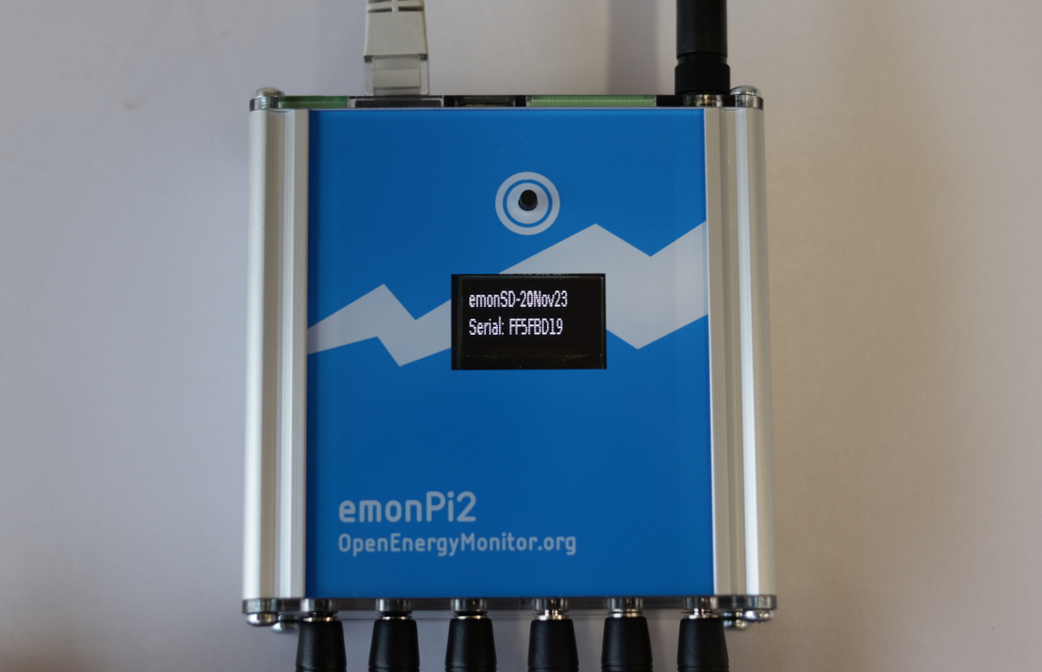
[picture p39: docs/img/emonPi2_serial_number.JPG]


Scroll through the display menu by pushing the button above the display. The menu items are:

1. emonSD image version and hardware serial number.
2. Time and date and uptime
3. Ethernet status (or if connected IP Address)
4. WiFi status (or if connected IP Address)
5. WiFi Access Point (AP) status and if enabled IP Address
6. Enable or Disable WiFi Access Point (press and hold for 5 seconds to change)
8. Enable or Disable SSH access (press and hold for 5 seconds to change)
9. Shutdown gracefully (press and hold for 5 seconds)

```{note}
When the emonPi2 is first powered up the WiFi Access Point is enabled for 10 minutes. Page 5 will show the WiFi Access Point as `WiFi AP: YES` followed by the access point IP address `192.168.42.1`. The access point is enabled at startup primarily for emonBase systems which do not have a push button, providing a way to configure or reconfigure WiFi during this startup window. It is possible to turn this off if prefered.
``` 

## 5. Connecting via Ethernet

If a wired ethernet connection is available and you have the emonPi2 hardware that supports Ethernet (e.g RaspberryPi 4 shop option), this does usually give the most reliable result. We recommend using shielded Etherent cable to reduce potential electromagnetic interference. Simply plug the Ethernet cable into the Ethernet port found next to the USB ports and CT sensor inputs - *NOT the RJ45 port used for the emonVs voltage sensor and power supply*.

Scroll to page 3 on the emonPi2 display to find the assigned IP address.

## 6. Connecting via WiFi

**When the emonPi2 is powered up it will create a Wi-Fi Access Point** called `emonPi`. Connect to this using password `emonpi2016`. On Android devices a captive portal option should pop up with the option to 'Sign in'. This will bring up the Wi-Fi configuration interface.

```{note}
Captive portal and the new Wifi setup interface is available on emonSD_01Feb24 or newer. You may wish to upgrade to the latest emonSD image see the emonSD download section.
```

```{note}
While captive portal generally works well on Android phones, the current software version may not always provide a consistent captive portal 'Sign in' popup on other devices and browsers. If no 'Sign in' option appears browse manually to the IP address [http://192.168.42.1](http://192.168.42.1).
```

1\. Click on 'Connect to WiFi network' to show the list of available WiFi networks. Click on the network that you wish to connect to.

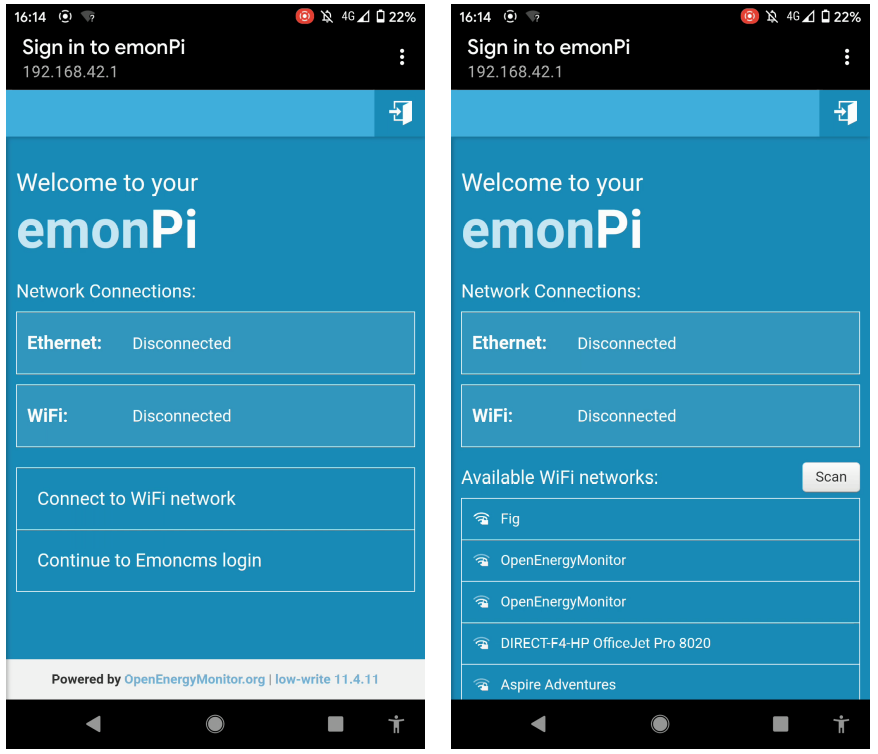
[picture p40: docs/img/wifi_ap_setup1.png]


2\. Enter the WiFi network passkey (often found at the back of the internet router). Click connect. Connecting to a network and relaying the status update back to the user interface typically takes around 20 seconds. Note down the assigned IP address and use this to connect to your emonPi2 once you are connected back to your home WiFi network.

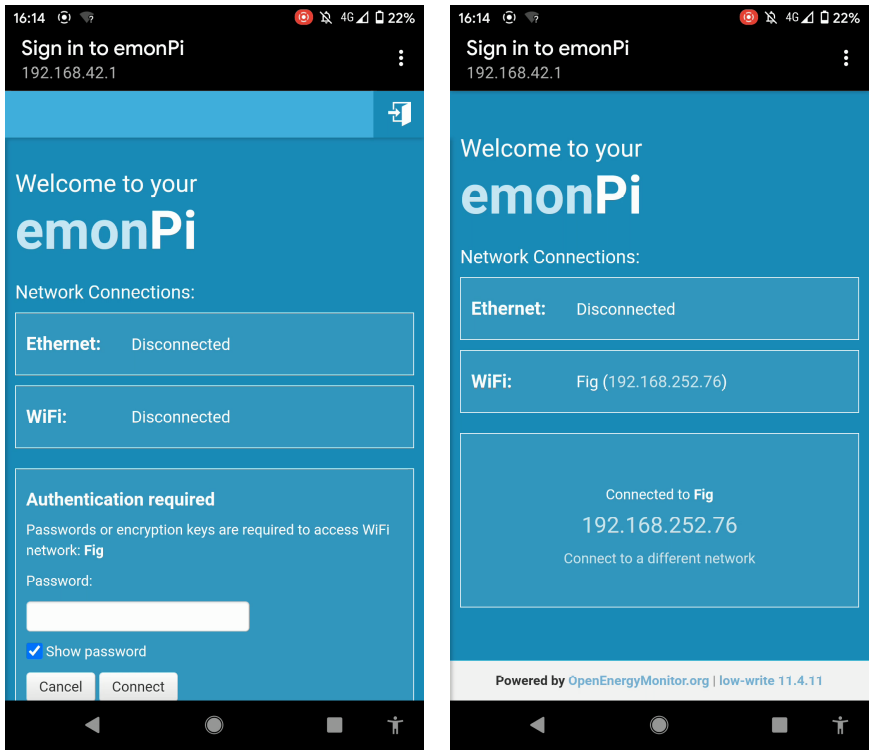
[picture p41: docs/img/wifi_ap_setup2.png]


```{note}
The Pi Zero 2W hardware option will usually drop the access point WiFi connection a few seconds after clicking 'Connect'. Wait a few seconds, disable and re-enable WiFi on your phone, connect to the emonPi access point again and then bring up the network configuration interface via the 'Sign in' captive portal if available. The connection status and IP address can be accessed by reconnecing to the access point in this way.
```

The WiFi IP address can also be accessed by scrolling to page 4 on the emonPi LCD:

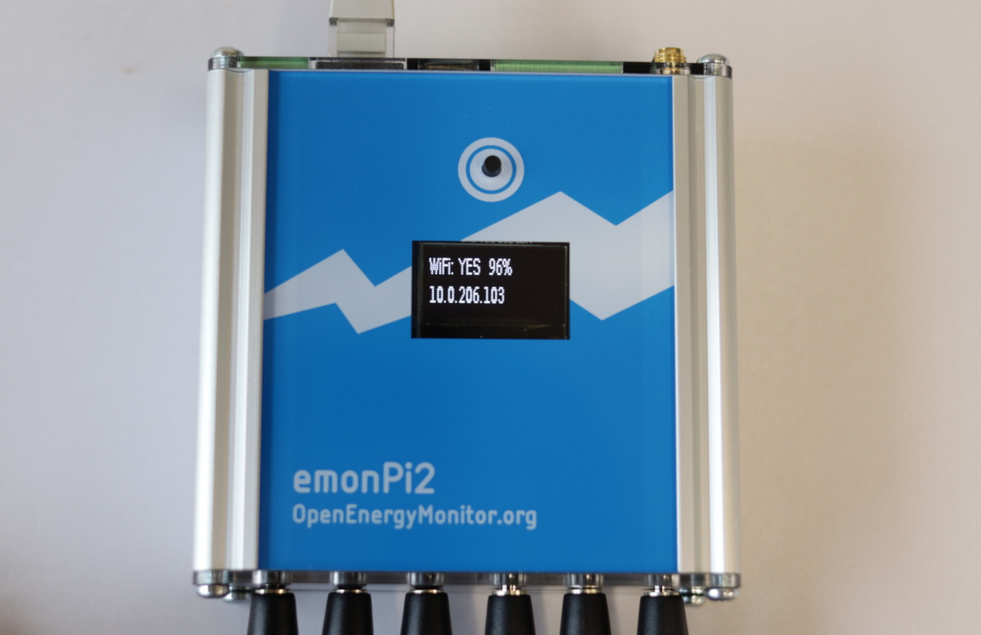
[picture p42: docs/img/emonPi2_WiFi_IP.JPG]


**The emonPi2 will now present the emoncms login screen.** If the Register button is not shown, login with default account username `emonsd` and password `emonsd`. We recommend changing the default username and password from the My Account page once logged in.

## 7. EmonCMS setup

EmonCMS is the main user interface on the emonPi/base, it can be used to store and visualise data locally or just used to configure posting data to a remote server, or both.

The following guides are a useful resource, detailing how to use and make the most of the EmonCMS application:

1. Start with [emonCMS: Getting started emonPi/Base](../emoncms/intro-rpi.md), this gives a useful overview of the main parts of Emoncms to familiarise with first. It discusses the difference between local and remote logging and introduces the emonHub software tool that is used alongside Emoncms to read data from the emonPi and any other connected sensors. See also the *Setup inputs and feeds* section below.

2. The [Emoncms core concepts guide](../emoncms/coreconcepts.md) is a useful overview of terminology. What is an input, feed, device? What the difference is between the graph tool, other visualisations, apps and dashboards.

3. There are number of pages that discuss how to use the EmonCMS graph tool: [View Graphs](../emoncms/graphs.md), [Calculating Averages](../emoncms/daily-averages.md), [Calculating Daily kWh](../emoncms/daily-kwh.md), [Exporting CSV data](../emoncms/export-csv.md).

## 8. CT calibration selection

Different rating CT sensors e.g 100A, 50A, 20A etc, require differant preset calibrations.

CT calibration is usually pre-configured in the shop as part of the order process, but you may wish to double check that your calibration configuration matches the sockets that you have plugged the CT sensors into at this point.

- Navigate to `Setup > Admin > Serial Config`
- Click on `Stop EmonHub` to temporarily stop the EmonHub service while we perform calibration.
- Select serial port `/dev/ttyAMA0` and click `Connect`.
- After a couple of seconds the emonPi2 will print out its current configuration which will populate the interface (if it does not do this type `l` and click `Send` to reload the calibration details from the emonPi2 measurement board).
- Adjust the  CT rating to match the CT sensor that you have installed on each channel.
- Click on `Save Changes` to ensure that the new configuration is recorded such that it persists when you power cycle the board.
- When finished, click on `Stop Serial` to disconnect the serial configuration tool and then `Start EmonHub` to restart the EmonHub service.



## 9. Setup input and feeds

**Configure inputs by navigating to Setup > Inputs.** The emonPi2 will pop up here automatically under the `EmonPi2` node name.

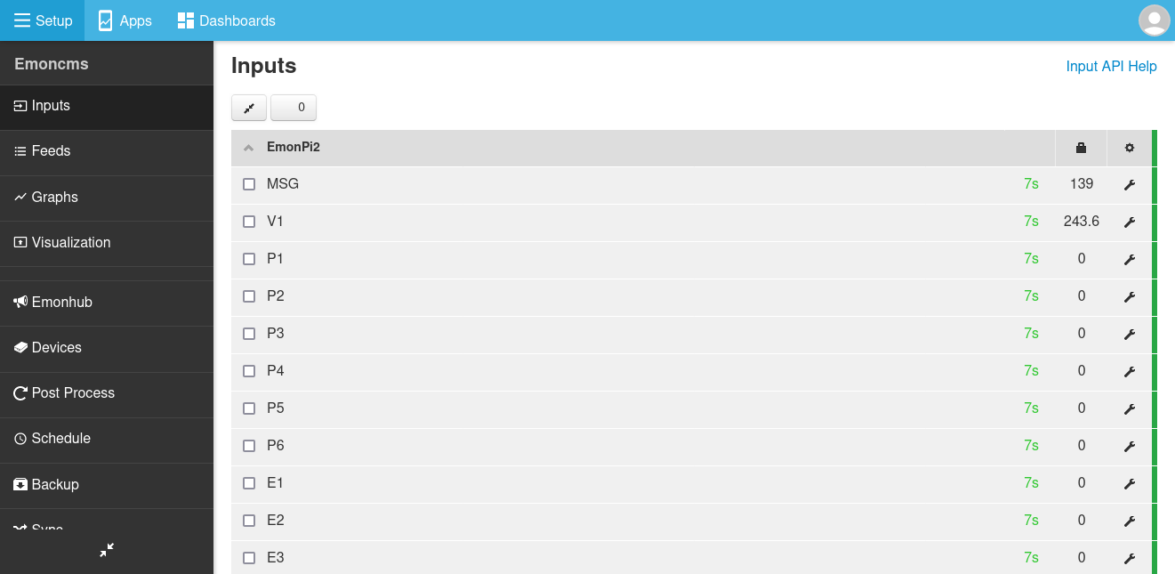
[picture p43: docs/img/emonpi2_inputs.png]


**The next step is to log the input data to feeds.** Inputs are just placeholders showing the latest values sent from the emonPi2, we need to create feeds if we want to record a time-series of these values. It’s possible to either manually configure each input as required, or if you just want to record everything for now and delete what you don’t need later, then you can use the pre-configured Device Template.

```{tip} 
**Input configuration using the emonPi2 device template:** On the Setup > Inputs page, Click on the cog icon (top right corner) of the emonPi2 node. The 'Configure Device' window will appear, click on 'emonPi2 Standard', you may need to scroll down a little in the Devices pane to find. Click 'Save' and 'Initialize'. This will create feeds that record real power and cumulative energy for each channel, Vrms, total message count, temperatures and total pulse count. Navigate to Setup > Feeds to see these feeds.
```

**Manual input configuration:** You may only want to record specific channels or apply more complex input processing.

**With feeds created, explore the data using the graph view.** Navigate to Setup > Feeds and click on a feed of interest to open the graph view. Click on the drop down time selector near the title and select the last hour. Click and drag to zoom further to see the new data coming in.

**Try creating an Emoncms App.** Click on the Apps tab. From the Available Apps list select 'My Electric' and click 'Create', Select a power feed for 'use' and cumulative kWh energy feed for 'use_kwh' and then click 'Launch App'. After a few days this will start to show a daily bar graph of consumption alongside the real-time power graph and totals. There are a wide variety of different app's to choose from depending on the application.

## 1 phase or 3 phase firmware? Pi Zero with the CT expansion board?

We will in most cases upload the relevant firmware in the shop that matches the order placed. But if you need to change the firmware configuration this is also very much an option with the emonPi2. Please see the [Frimware](firmware.md) page for details about the different options.

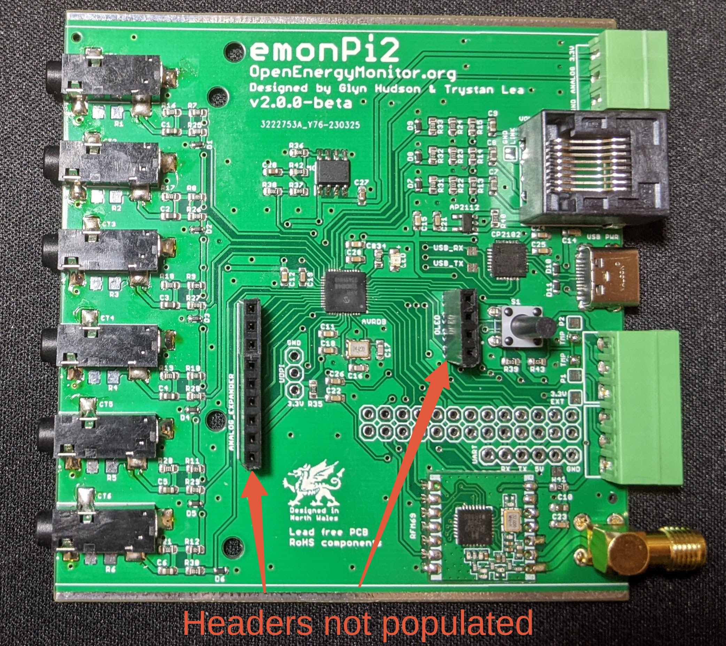
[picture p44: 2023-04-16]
hardware/assembled_photo.jpg

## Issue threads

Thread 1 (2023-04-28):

Custom Pi configuration steps to resolve

TrystanLea, 2023-04-28:
1\. Change DS18B20 OneWire pin

    sudo nano /boot/config.txt

change to:

    [all]
    dtoverlay=w1-gpio,gpiopin=17

3\. Switch to emonpi2.default.emonhub.conf

Closed 2023-11-20.

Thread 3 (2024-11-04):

emonPi2 RJ45 pin assignment shorts out emonVs

pevsonic, 2024-11-04:
I've had an issue where I've got an emonVs (v1.1) and having picked up and emonPi (v2.0.1) the AC voltage sense wasn't working.

I've traced through the schematics and it looks like the RJ45 pinnings on the emonPi2 aren't ideal. RJ11 and RJ45 are by design backwards compatible physically but it seems this hasn't been taken into account with the emonPi2 pinnings. When I connect the emonVs and emonPi2 together, the following occurs :

```
                        n/c -> emonPi2 v2.0.1 Pin 1 (VS1)
emonVs 1.1 RJ11 pin 1 (GND) -> emonPi2 v2.0.1 Pin 2 (VS2)
emonVs 1.1 RJ11 pin 2 (5v)  -> emonPi2 v2.0.1 Pin 3 (VS3)
emonVs 1.1 RJ11 pin 3 (n/c) -> emonPi2 v2.0.1 Pin 4 (+5v)
emonVs 1.1 RJ11 pin 4 (VS3) -> emonPi2 v2.0.1 Pin 5 (+5v)
emonVs 1.1 RJ11 pin 5 (VS2) -> emonPi2 v2.0.1 Pin 6 (GND - LINK)
emonVs 1.1 RJ11 pin 6 (VS1) -> emonPi2 v2.0.1 Pin 7 (GND)
                        n/c -> emonPi2 v2.0.1 Pin 8 (GND)
```

i.e. my VS1 is getting pulled to deck... If metered disconnected I was seeing 0.3v as expected - when linked, this gets pulled down to 0.18v... Not to mention being on the wrong pin... I’m glad nothing went pop!

Unless Im missing something really obvious, the emonPi2 RJ45 pinning would ideally be the following to allow backwards compatibility :

```
                        n/c -> emonPi2 v2.0.1 Pin 1 (GND)
emonVs 1.1 RJ11 pin 1 (GND) -> emonPi2 v2.0.1 Pin 2 (GND)
emonVs 1.1 RJ11 pin 2 (5v)  -> emonPi2 v2.0.1 Pin 3 (+5v)
emonVs 1.1 RJ11 pin 3 (n/c) -> emonPi2 v2.0.1 Pin 4 (GND - LINK)
emonVs 1.1 RJ11 pin 4 (VS3) -> emonPi2 v2.0.1 Pin 5 (VS3)
emonVs 1.1 RJ11 pin 5 (VS2) -> emonPi2 v2.0.1 Pin 6 (VS2)
emonVs 1.1 RJ11 pin 6 (VS1) -> emonPi2 v2.0.1 Pin 7 (VS1)
                        n/c -> emonPi2 v2.0.1 Pin 8 (+5v)
```

TrystanLea, 2024-11-05:
Hello @pevsonic, thanks for your thoughts on this,  interesting thought, an RJ11 to RJ45 adapter in the way you describe was not something that I had thought about to be honest. The main focus in my mind at the time was trying to avoid issues if the emonVs RJ45 was plugged into an internet router, or the ethernet port on the RaspberryPi, whilst also selecting a pin our that provided for cleaner board routing I think..

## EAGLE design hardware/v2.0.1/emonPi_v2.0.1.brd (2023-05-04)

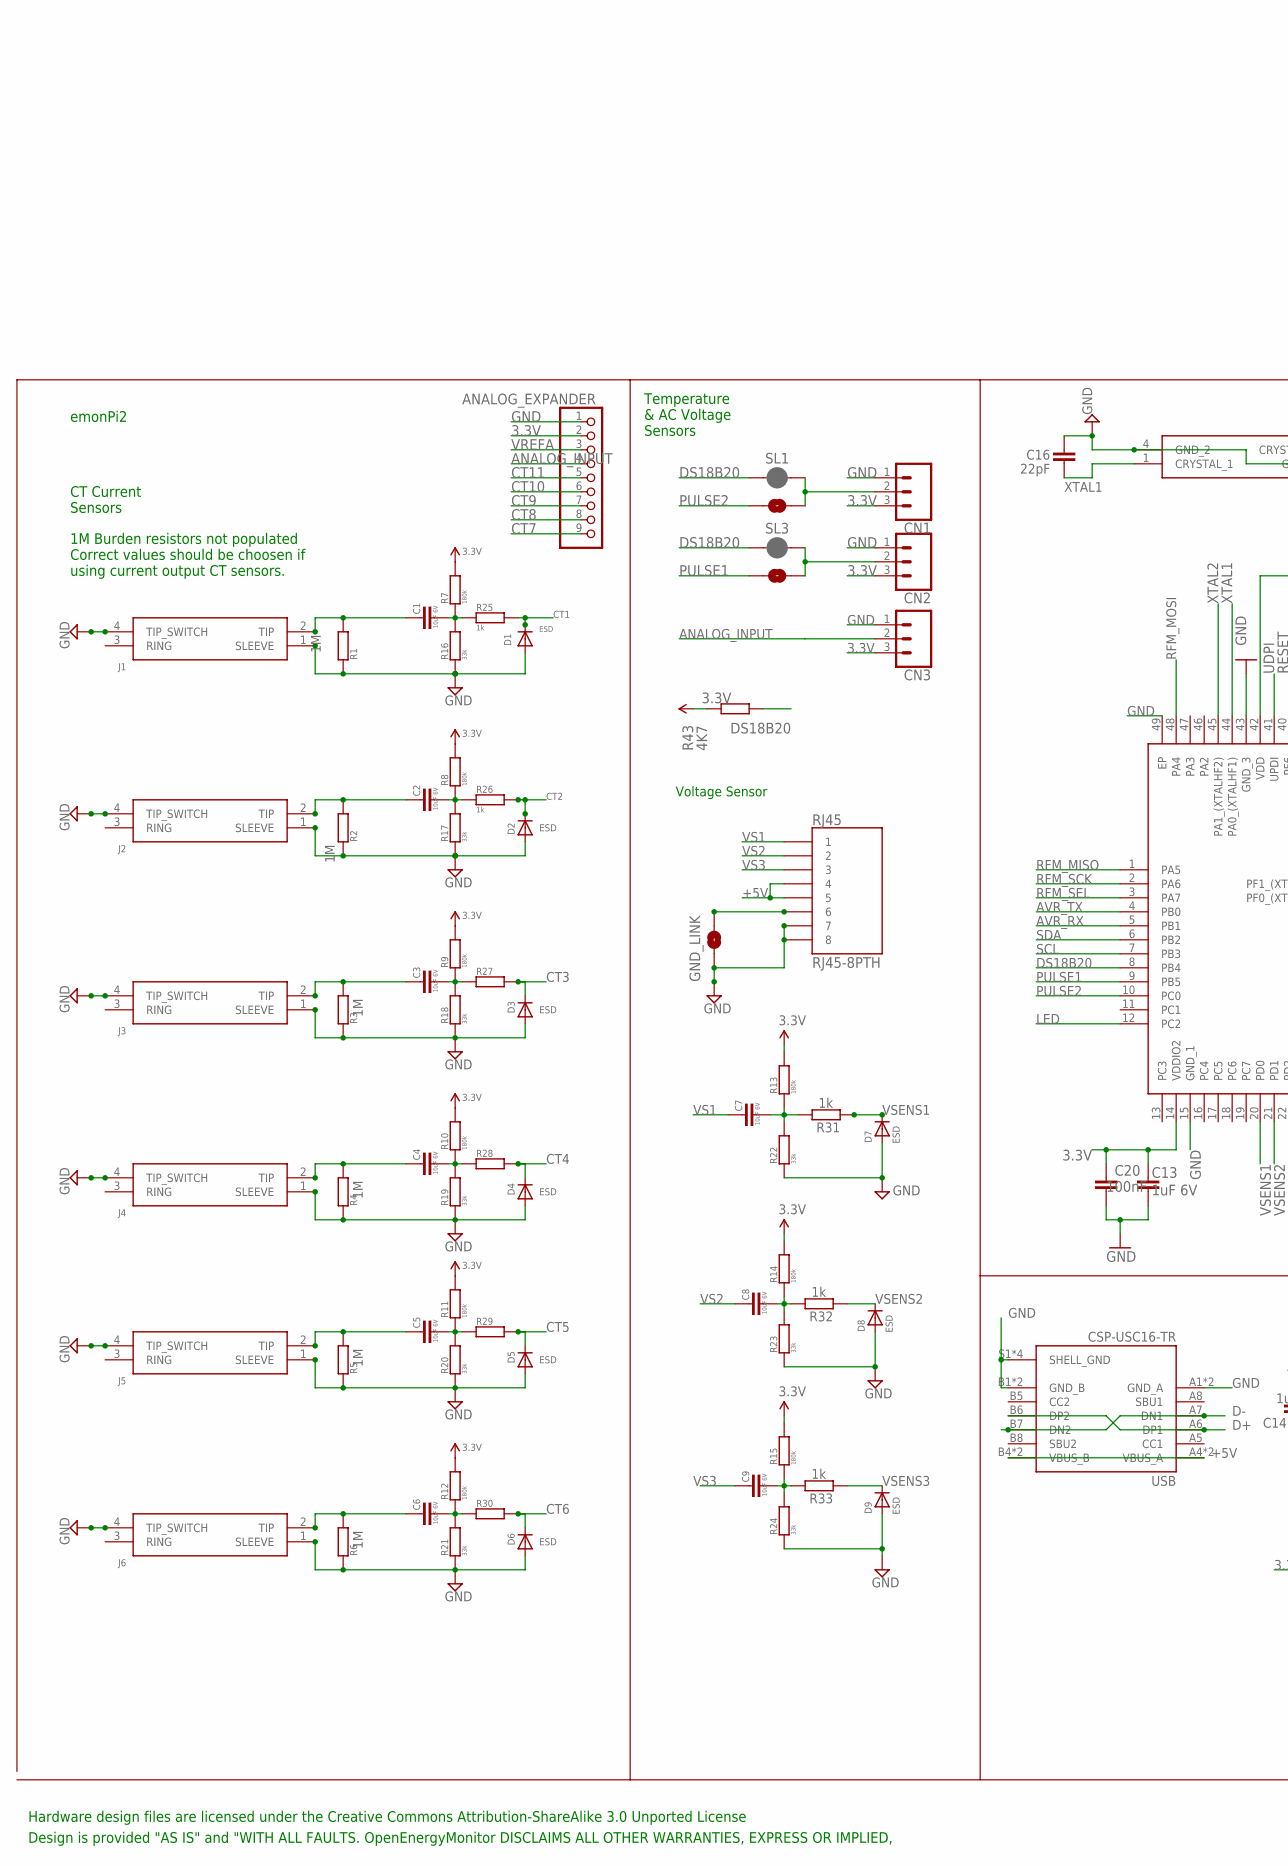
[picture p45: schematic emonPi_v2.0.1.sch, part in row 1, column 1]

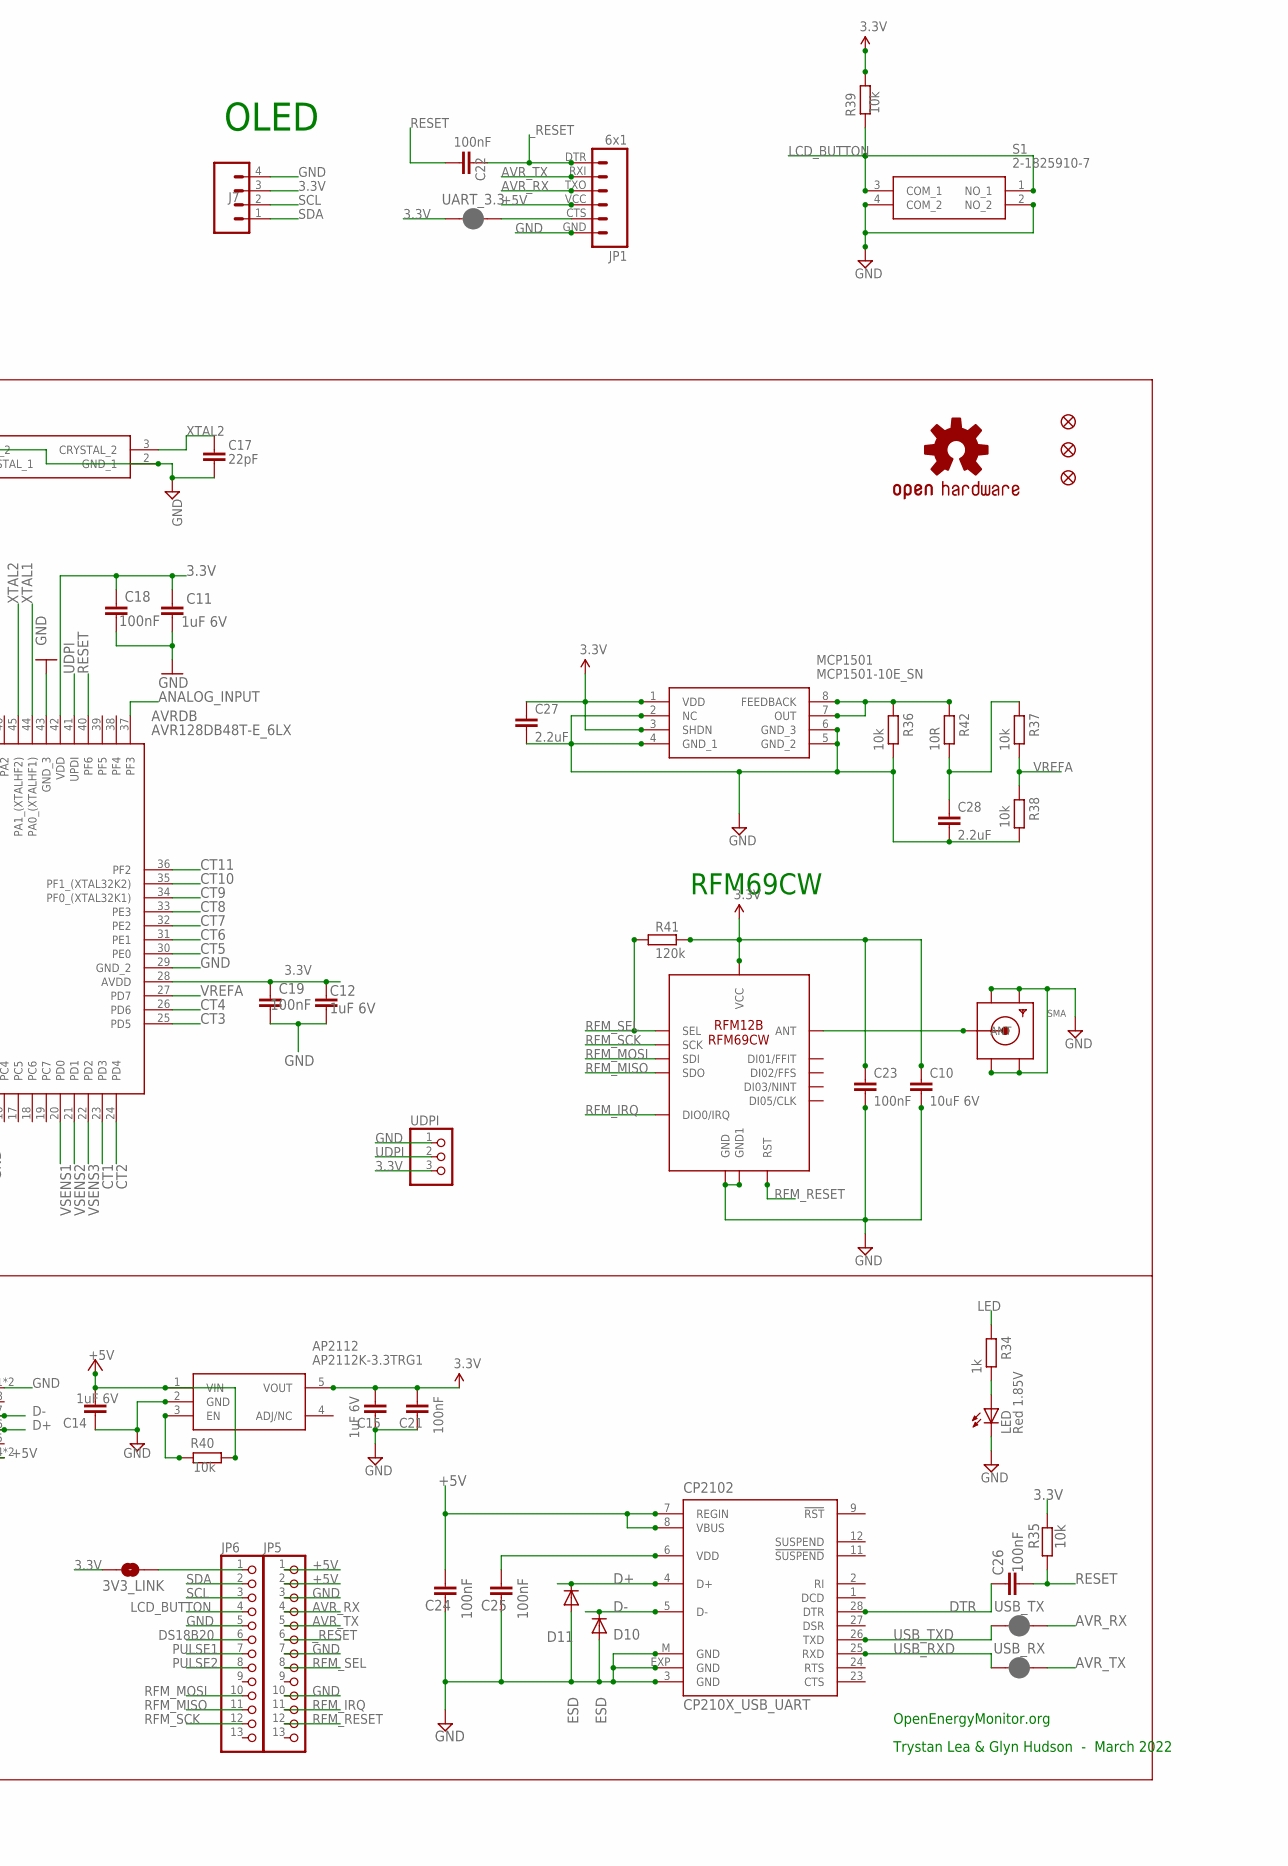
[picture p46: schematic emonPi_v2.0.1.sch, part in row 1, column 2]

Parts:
3V3_LINK: SOLDERJUMPERNC; SJ_2S
ANALOG_EXPANDER: PINHD-1X9; 1X09-BIG
AP2112: AP2112K-3.3TRG1; SOT95P282X130-5N
AVRDB: AVR128DB48T-E_6LX; QFN40P600X600X90-49N
C1, C2, C3, C4, C5, C6, C7, C8, C9, C10: 10uF 6V; C0603
C11, C12, C13, C14, C15: 1uF 6V; C0603
C16, C17: 22pF; C0603
C18, C19, C20, C21, C22, C23, C24, C25, C26: 100nF; C0603
C27, C28: 2.2uF; C0603
CN1, CN2, CN3: CONN_03SCREW; SCREWTERMINAL-3.5MM-3
CP2102: CP210X_USB_UART; MLP28
D1, D2, D3, D4, D5, D6, D7, D8, D9, D10, D11: ESD; SOD-523
FD1, FD2, FD3: FIDUCIAL1X2; FIDUCIAL-1X2
GND_LINK: SOLDERJUMPERNC; SJ_2S
J1, J2, J3, J4, J5, J6: SJ-3524-SMT-TR
J7: CONN_04PTH; 1X04
JP1: 6x1; FTDI_BASIC
JP5, JP6: PINHD-1X13_BIG; 1X13-BIG
LED: Red 1.85V; CHIP-LED0805
LOGO1: OSHW-LOGOS-COPPER; OSHW-LOGO-S_COPPER
MCP1501: MCP1501-10E_SN; SOIC127P600X175-8N
R1, R2, R3, R4, R5, R6: 1M; R1206
R7, R8, R9, R10, R11, R12, R13, R14, R15: 180k; R0603
R16, R17, R18, R19, R20, R21, R22, R23, R24: 33k; R0603
R25, R26, R27, R28, R29, R30, R31, R32, R33, R34: 1k; R0603
R35, R36, R37, R38, R39, R40: 10k; R0603
R41: 120k; R0603
R42: 10R; R0603
R43: 4K7; R0603
RFM69: RFM12B/69CW
RJ45: RJ45-8PTH; RJ45-8
S1: 2-1825910-7; 218259107
SL1, SL3: JUMPER-SMT_2_NC_PASTE_NO-SILK; SMT-JUMPER_2_NC_PASTE_NO-SILK
SL2, SL4: SOLDERJUMPERNC; SJ_2S
SMA: SMACONNECTOR; SMA90_DIP
UART_3.3: JUMPER-SMT_2_NC_PASTE_NO-SILK; SMT-JUMPER_2_NC_PASTE_NO-SILK
UDPI: PINHD-1X3; 1X03
USB: CSP-USC16-TR; VALCON_CSP-USC16-TR
USB_RX: JUMPER-SMT_2_NC_PASTE_NO-SILK; SMT-JUMPER_2_NC_PASTE_NO-SILK
USB_TX: JUMPER-SMT_2_NC_PASTE_NO-SILK; SMT-JUMPER_2_NC_PASTE_NO-SILK
XTAL: MCSJK-7U-12.00-12-10-80-B-10; MCSJK7U1200121080B10

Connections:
3.3V: 3V3_LINK.1, ANALOG_EXPANDER.2, AP2112.5 (VOUT), AVRDB.14 (VDDIO2), AVRDB.28 (AVDD), AVRDB.42 (VDD), C10.1, C11.1, C12.1, C13.1, C15.2, C18.1, C19.1, C20.1, C21.2, C23.1, C27.1, CN1.3, CN2.3, CN3.3, J7.3, MCP1501.1 (VDD), MCP1501.3 (SHDN), R7.2, R8.2, R9.2, R10.2, R11.2, R12.2, R13.2, R14.2, R15.2, R35.2, R39.1, R41.2, R43.1, RFM69.VDD (VCC), UART_3.3.1, UDPI.3
+5V: AP2112.1 (VIN), C14.2, C24.2, CP2102.7 (REGIN), CP2102.8 (VBUS), JP1.VCC (4), JP5.1, JP5.2, R40.1, RJ45.4, RJ45.5, USB.A4 (VBUS_A), USB.A9 (VBUS_A), USB.B4 (VBUS_B), USB.B9 (VBUS_B)
ANALOG_INPUT: ANALOG_EXPANDER.4, AVRDB.37 (PF3), CN3.2
AVR_RX: AVRDB.5 (PB1), JP1.TXO (3), JP5.4, USB_TX.2
AVR_TX: AVRDB.4 (PB0), JP1.RXI (2), JP5.5, USB_RX.2
CT1: AVRDB.23 (PD3), D1.K (C), R25.2
CT2: AVRDB.24 (PD4), D2.K (C), R26.2
CT3: AVRDB.25 (PD5), D3.K (C), R27.1
CT4: AVRDB.26 (PD6), D4.K (C), R28.1
CT5: AVRDB.30 (PE0), D5.K (C), R29.1
CT6: AVRDB.31 (PE1), D6.K (C), R30.1
CT7: ANALOG_EXPANDER.9, AVRDB.32 (PE2)
CT8: ANALOG_EXPANDER.8, AVRDB.33 (PE3)
CT9: ANALOG_EXPANDER.7, AVRDB.34 (PF0_(XTAL32K1))
CT10: ANALOG_EXPANDER.6, AVRDB.35 (PF1_(XTAL32K2))
CT11: ANALOG_EXPANDER.5, AVRDB.36 (PF2)
D+: CP2102.4 (D+), D11.K (C), USB.A6 (DP1), USB.B6 (DP2)
D-: CP2102.5 (D-), D10.K (C), USB.A7 (DN1), USB.B7 (DN2)
DIG1: RFM69.ANT, SMA.ANTENNA (ANT)
DS18B20: AVRDB.8 (PB4), JP6.6, R43.2, SL1.1, SL3.1
DTR: C26.1, CP2102.28 (DTR)
GND: ANALOG_EXPANDER.1, AP2112.2 (GND), AVRDB.15 (GND_1), AVRDB.29 (GND_2), AVRDB.43 (GND_3), AVRDB.49 (EP), C10.2, C11.2, C12.2, C13.2, C14.1, C15.1, C16.1, C17.2, C18.2, C19.2, C20.2, C21.1, C23.2, C24.1, C25.1, C27.2, C28.2, CN1.1, CN2.1, CN3.1, CP2102.3 (GND), CP2102.EXP (GND), CP2102.M (GND), D1.A, D2.A, D3.A, D4.A, D5.A, D6.A, D7.A, D8.A, D9.A, D10.A, D11.A, GND_LINK.1, J1.1 (SLEEVE), J1.4 (TIP_SWITCH), J2.1 (SLEEVE), J2.4 (TIP_SWITCH), J3.1 (SLEEVE), J3.4 (TIP_SWITCH), J4.1 (SLEEVE), J4.4 (TIP_SWITCH), J5.1 (SLEEVE), J5.4 (TIP_SWITCH), J6.1 (SLEEVE), J6.4 (TIP_SWITCH), J7.4, JP1.GND (6), JP5.3, JP5.7, JP5.10, JP6.5, LED.C, MCP1501.2 (NC), MCP1501.4 (GND_1), MCP1501.5 (GND_2), MCP1501.6 (GND_3), R1.1, R2.1, R3.1, R4.1, R5.1, R6.1, R16.2, R17.2, R18.2, R19.2, R20.2, R21.2, R22.2, R23.1, R24.1, R36.1, R38.1, RFM69.GND, RFM69.GND1, RJ45.7, RJ45.8, S1.2 (NO_2), S1.4 (COM_2), SMA.GND1, SMA.GND2, SMA.GND3, SMA.GND4, UDPI.1, USB.A1 (GND_A), USB.A12 (GND_A), USB.B1 (GND_B), USB.B12 (GND_B), USB.S1 (SHELL_GND), USB.S2 (SHELL_GND), USB.S3 (SHELL_GND), USB.S4 (SHELL_GND), XTAL.2 (GND_1), XTAL.4 (GND_2)
LCD_BUTTON: JP6.4, R39.2, S1.1 (NO_1), S1.3 (COM_1)
LED: AVRDB.12 (PC2), R34.2
unnamed: C1.1, J1.2 (TIP), R1.2
unnamed: C7.2, R13.1, R22.1, R31.2
unnamed: C3.1, J3.2 (TIP), R3.2
unnamed: C8.2, R14.1, R23.2, R32.2
unnamed: C4.1, J4.2 (TIP), R4.2
unnamed: C9.2, R15.1, R24.2, R33.2
unnamed: C2.1, J2.2 (TIP), R2.2
unnamed: C5.1, J5.2 (TIP), R5.2
unnamed: C5.2, R11.1, R20.1, R29.2
unnamed: C2.2, R8.1, R17.1, R26.1
unnamed: C4.2, R10.1, R19.1, R28.2
unnamed: C1.2, R7.1, R16.1, R25.1
unnamed: C6.1, J6.2 (TIP), R6.2
unnamed: C6.2, R12.1, R21.1, R30.2
unnamed: C3.2, R9.1, R18.1, R27.2
unnamed: CN1.2, SL1.2, SL2.2
unnamed: CN2.2, SL3.2, SL4.2
unnamed: GND_LINK.2, RJ45.6
unnamed: AP2112.3 (EN), R40.2
unnamed: C28.1, R37.2, R42.1
unnamed: MCP1501.7 (OUT), MCP1501.8 (FEEDBACK), R36.2, R42.2
unnamed: 3V3_LINK.2, JP6.1
unnamed: C25.2, CP2102.6 (VDD)
unnamed: JP1.CTS (5), UART_3.3.2
unnamed: LED.A, R34.1
PULSE1: AVRDB.9 (PB5), JP6.7, SL4.1
PULSE2: AVRDB.10 (PC0), JP6.8, SL2.1
RESET: AVRDB.40 (PF6), C22.2, C26.2, R35.1
RFM_IRQ: JP5.11, RFM69.IRQ (DIO0/IRQ)
RFM_MISO: AVRDB.1 (PA5), JP6.11, RFM69.SDO
RFM_MOSI: AVRDB.48 (PA4), JP6.10, RFM69.SDI
RFM_RESET: JP5.12, RFM69.RST
RFM_SCK: AVRDB.2 (PA6), JP6.12, RFM69.SCK
RFM_SEL: AVRDB.3 (PA7), JP5.8, R41.1, RFM69.SEL
SCL: AVRDB.7 (PB3), J7.2, JP6.3
SDA: AVRDB.6 (PB2), J7.1, JP6.2
UDPI: AVRDB.41 (UPDI), UDPI.2
USB_RXD: CP2102.25 (RXD), USB_RX.1
USB_TXD: CP2102.26 (TXD), USB_TX.1
VREFA: ANALOG_EXPANDER.3, AVRDB.27 (PD7), R37.1, R38.2
VS1: C7.1, RJ45.1
VS2: C8.1, RJ45.2
VS3: C9.1, RJ45.3
VSENS1: AVRDB.20 (PD0), D7.K (C), R31.1
VSENS2: AVRDB.21 (PD1), D8.K (C), R32.1
VSENS3: AVRDB.22 (PD2), D9.K (C), R33.1
XTAL1: AVRDB.44 (PA0_(XTALHF1)), C16.2, XTAL.1 (CRYSTAL_1)
XTAL2: AVRDB.45 (PA1_(XTALHF2)), C17.1, XTAL.3 (CRYSTAL_2)
_RESET: C22.1, JP1.DTR (1), JP5.6

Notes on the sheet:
Voltage Sensor
RFM69CW
OLED
emonPi2
Temperature & AC Voltage Sensors
Design is provided "AS IS" and "WITH ALL FAULTS. OpenEnergyMonitor DISCLAIMS ALL OTHER WARRANTIES, EXPRESS OR IMPLIED,
Hardware design files are licensed under the Creative Commons Attribution-ShareAlike 3.0 Unported License
OpenEnergyMonitor.org
Trystan Lea & Glyn Hudson - March 2022
1M Burden resistors not populated Correct values should be choosen if using current output CT sensors.
CT Current Sensors

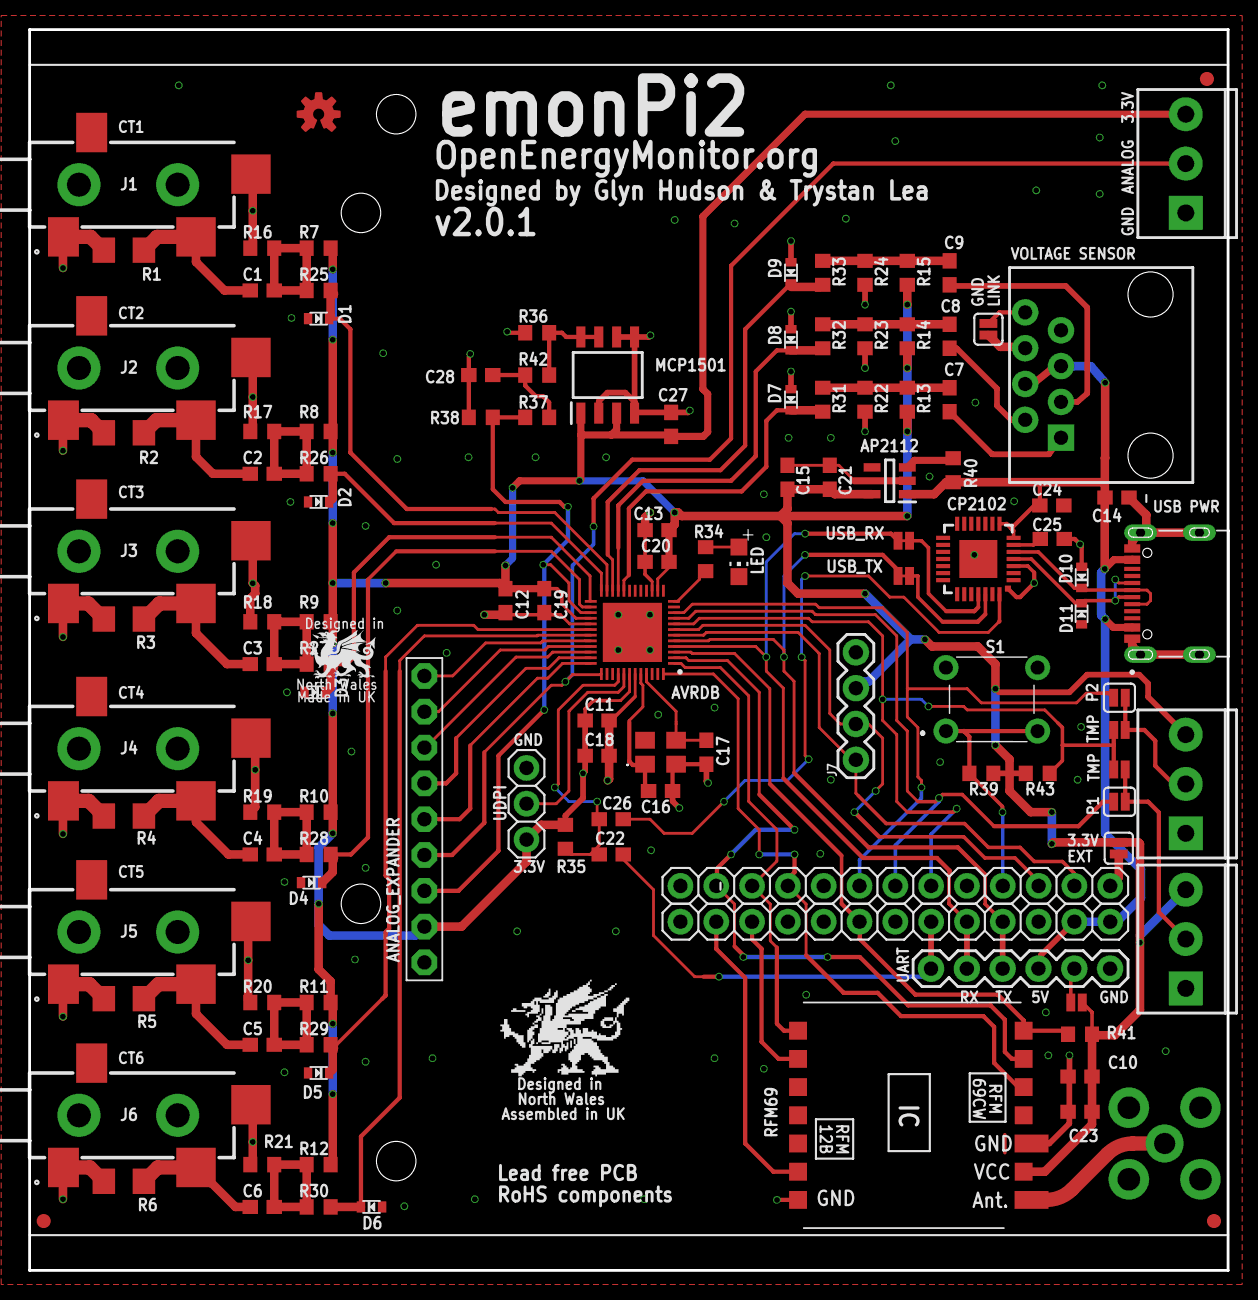
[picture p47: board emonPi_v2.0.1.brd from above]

Board: 2 copper layers, 85.0 x 88.0 mm, 121 parts (0 on the bottom side), 73 nets.

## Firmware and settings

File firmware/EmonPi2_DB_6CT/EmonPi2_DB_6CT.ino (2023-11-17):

/*
  emonPi2 Continuous Sampling
  using EmonLibCM https://github.com/openenergymonitor/EmonLibCM
  Authors: Robin Emley, Robert Wall, Trystan Lea
  
  -----------------------------------------
  Part of the openenergymonitor.org project
  Licence: GNU GPL V3



Change Log:
v1.0.0: First release of EmonPi2 DB Continuous Monitoring Firmware (based on EmonTx4 DB Firmware)

*/
#define Serial Serial3

#include <Wire.h>
#include "SSD1306Ascii.h"
#include "SSD1306AsciiWire.h"
SSD1306AsciiWire oled;

#define RFM69_JEELIB_CLASSIC 1
#define RFM69_JEELIB_NATIVE 2
#define RFM69_LOW_POWER_LABS 3

#define RadioFormat RFM69_LOW_POWER_LABS

const char *firmware_version = {"1.0.1\n\r"};
/*

emonhub.conf node decoder (nodeid is 27 when switch is off, 18 when switch is on)
See: https://github.com/openenergymonitor/emonhub/blob/emon-pi/configuration.md
copy the following into emonhub.conf:

[[27]]
  nodename = EmonPi2_DB
  [[[rx]]]
    names = MSG, V1, V2, V3, P1, P2, P3, P4, P5, P6, E1, E2, E3, E4, E5, E6, pulse
    datacodes = L, h,h,h, h,h,h,h,h,h, l,l,l,l,l,l ,L
    scales = 1,0.01,0.01,0.01,1,1,1,1,1,1,1,1,1,1,1
    units = n,V,V,V,W,W,W,W,W,W,Wh,Wh,Wh,Wh,Wh,Wh,p

*/
// Comment/Uncomment as applicable
#define DEBUG                                              // Debug level print out
#define EMONTX4

// #define EEWL_DEBUG

#define OFF HIGH
#define ON LOW

#define RFM69CW

#include <Arduino.h>
#include <avr/wdt.h>

#if RadioFormat == RFM69_LOW_POWER_LABS
  #include "RFM69_LPL.h"
#else
  #include "RFM69_JeeLib.h"                                        // Minimal radio library that supports both original JeeLib format and later native format
#endif

// EEWL_START = 102, Start EEPROM wear leveling section after config section which takes up first 99 bytes, a few bytes of padding here
// EEWL_BLOCKS = 14, 14 x 29 byte blocks = 406 bytes. EEWL_END = 102+406 = 508 a few bytes short of 512 byte limit
// EEWL is only updated if values change by more than 200Wh, this means for a typical house consuming ~4000kWh/year
// 20,000 writes per channel to EEPROM, there's a 100,000 write lifetime for any individual EEPROM byte.
// With a circular buffer of 14 blocks, this extends the lifetime from 5 years to 70 years.
// IMPORTANT! If adding to config section change EEWL_START and check EEWL_END Implications.

#include <emonEProm.h>                                     // OEM EEPROM library
#include <emonLibDB.h>                                     // OEM Continuous Monitoring library DB

// Include EmonPi2_DB_6CT_config.ino in the same directory for settings functions & data

RFM69 rf;

#define NUM_V_CHANNELS 1                                   // SET TO 1 FOR SINGLE PHASE
#define NUM_I_CHANNELS 6

// 50 Bytes
typedef struct {
    unsigned long Msg;
    int V[NUM_V_CHANNELS];
    int P[NUM_I_CHANNELS];
    long E[NUM_I_CHANNELS]; 
    // int T1,T2,T3;
    unsigned long pulse;
} PayloadTX;                                               // create a data packet for the RFM
PayloadTX emonpi;

static void showString (PGM_P s);
 
//---------------------------- emonPi2 Settings - Stored in EEPROM and shared with config.ino ------------------------------------------------
struct {
  byte RF_freq = RF69_433MHZ;                              // Frequency of radio module can be RFM_433MHZ, RFM_868MHZ or RFM_915MHZ. 
  byte networkGroup = 210;                                 // wireless network group, must be the same as emonBase / emonPi and emonGLCD. OEM default is 210
  byte nodeID = 27;                                        // node ID for this emonPi2.
  byte rf_on = 0;                                          // RF - 0 = no RF, 1 = RF on.
  byte rfPower = 25;                                       // 7 = -10.5 dBm, 25 = +7 dBm for RFM12B; 0 = -18 dBm, 31 = +13 dBm for RFM69CW. Default = 25 (+7 dBm)
  float vCal  = 101.3;                                     // Only single vCal for three phase in this firmware
  // float assumedVrms = 240.0;                            // Assumed Vrms when no a.c. is detected
  float lineFreq = 50;                                     // Line Frequency = 50 Hz

  float iCal[NUM_I_CHANNELS];
  float iLead[NUM_I_CHANNELS];
  
  float period = 9.8;                                      // datalogging period - should be fractionally less than the PHPFINA database period in emonCMS
  bool  pulse_enable = true;                               // pulse counting
  int   pulse_period = 100;                                // pulse min period - 0 = no de-bounce
  bool  showCurrents = false;                              // Print to serial voltage, current & p.f. values
  bool  json_enabled = false;                              // JSON Enabled - false = key,Value pair, true = JSON, default = false: Key,Value pair.  
} EEProm;

uint16_t eepromSig = 0x0010;                               // oemEProm signature - see oemEProm Library documentation for details.
 
#ifdef EEWL_DEBUG
  extern EEWL EVmem;
#endif

bool  USA=false;

bool calibration_enable = true;                           // Enable on-line calibration when running. 
                                                           // For safety, thus MUST default to false. (Required due to faulty ESP8266 software.)

//----------------------------emonPi2 hard-wired connections-----------------------------------
const byte LEDpin      = PIN_PC2;  // emonPi2 LED
//----------------------------------------Setup--------------------------------------------------
void setup() 
{  
  delay(1000);
  Wire1.swap(2);
  Wire1.begin();
  Wire1.setClock(400000L);

  oled.begin(&Adafruit128x64, 0x3C);

  oled.setFont(CalLite24);
  oled.setLetterSpacing(2);

  oled.clear();
  oled.setCursor(15,1);
  oled.print("emonPi2");
  oled.setFont(Arial14);
  oled.setCursor(40,6);

  oled.print("starting...");
  Wire1.end();
  
  pinMode(PIN_PB2,INPUT);
  pinMode(PIN_PB3,INPUT);
  
  //wdt_enable(WDTO_8S);
  
  pinMode(LEDpin, OUTPUT);
  digitalWrite(LEDpin,HIGH);
  
  // Serial---------------------------------------------------------------------------------
  Serial.begin(115200);
  // ---------------------------------------------------------------------------------------
  
  #ifdef DEBUG
    Serial.print(F("emonPi2 DB Continuous Monitoring V")); Serial.write(firmware_version);
    Serial.println(F("OpenEnergyMonitor.org"));
  #else
    Serial.println(F("describe:EmonPi2DB"));
  #endif

  for (byte ch=0; ch<NUM_I_CHANNELS; ch++) {
    EEProm.iCal[ch] = 20.0;
    EEProm.iLead[ch] = 3.2;
  }
 
  load_config(true);                                                   // Load RF config from EEPROM (if any exists)
  
  if (EEProm.rf_on)
  {
    #ifdef DEBUG
      #ifdef RFM12B
      Serial.print(F("RFM12B "));
      #endif
      #ifdef RFM69CW
      Serial.print(F("RFM69CW "));
      #endif
      Serial.print(F(" Freq: "));
      if (EEProm.RF_freq == RF69_433MHZ) Serial.print(F("433MHz"));
      if (EEProm.RF_freq == RF69_868MHZ) Serial.print(F("868MHz"));
      if (EEProm.RF_freq == RF69_915MHZ) Serial.print(F("915MHz"));
      Serial.print(F(" Group: ")); Serial.print(EEProm.networkGroup);
      Serial.print(F(" Node: ")); Serial.print(EEProm.nodeID);
      Serial.println(F(" "));
    #endif

    #if RadioFormat == RFM69_LOW_POWER_LABS
      Serial.println("RadioFormat: LowPowerLabs");
    #elif RadioFormat == RFM69_JEELIB_CLASSIC
      Serial.println("RadioFormat: JeeLib Classic");
    #elif RadioFormat == RFM69_JEELIB_NATIVE
      Serial.println("RadioFormat: JeeLib Native");
    #endif
  }
  // ---------------------------------------------------------------------------------------

  if (EEProm.rf_on)
  {
    #if RadioFormat == RFM69_JEELIB_CLASSIC
      rf.format(RFM69_JEELIB_CLASSIC);
    #endif
    
    // Frequency is currently hardcoded to 433Mhz in library
    #if RadioFormat == RFM69_LOW_POWER_LABS
    rf.setPins(PIN_PA7,PIN_PA4,PIN_PA5,PIN_PA6);
    #endif
    rf.initialize(RF69_433MHZ, EEProm.nodeID, EEProm.networkGroup); 
    rf.encrypt("89txbe4p8aik5kt3");                                    // ignored if jeelib classic
    delay(random(EEProm.nodeID * 20));                                 // try to avoid r.f. collisions at start-up
  }
  
  // ---------------------------------------------------------------------------------------
      
#ifdef EEWL_DEBUG
  EVmem.dump_buffer();
#endif

  double reference = read_reference();
  Serial.print(F("Reference voltage calibration: "));
  Serial.println(reference,4);

  /****************************************************************************
  *                                                                           *
  * Set the properties of the physical sensors                                *
  *                                                                           *
  ****************************************************************************/
  
  EmonLibDB_set_vInput(1, EEProm.vCal, 0.16);         // emonVS Input channel 1, voltage calibration 100, phase error 0.16°
  #if NUM_V_CHANNELS == 3
    EmonLibDB_set_vInput(2, EEProm.vCal, 0.16);       // emonVS Input channel 2, voltage calibration 100, phase error 0.16°
    EmonLibDB_set_vInput(3, EEProm.vCal, 0.16);       // emonVS Input channel 3, voltage calibration 100, phase error 0.16°
  #endif
                                                      // (All 3 may be set, even if those inputs are unused)

  for (byte ch=0; ch<NUM_I_CHANNELS; ch++) {
    EmonLibDB_set_cInput(ch+1, EEProm.iCal[ch], EEProm.iLead[ch]);         
  }

  /****************************************************************************
  *                                                                           *
  * Link voltage and current sensors to define the power                      *
  *  & energy measurements                                                    *
  *                                                                           *
  * For best precision and performance, include only the following lines      *
  *    that apply to current/power inputs being used.                         *
  ****************************************************************************/

  #if NUM_V_CHANNELS == 3
    
    EmonLibDB_set_pInput(1, 1); // Phase 1
    EmonLibDB_set_pInput(2, 1); // Phase 2
    EmonLibDB_set_pInput(3, 1); // Phase 3
    EmonLibDB_set_pInput(4, 1); // Phase 1
    EmonLibDB_set_pInput(5, 1); // Phase 2
    EmonLibDB_set_pInput(6, 1); // Phase 3
    /*
    EmonLibDB_set_pInput(1, 1, 2);               // CT1 between V1 & V2    
    EmonLibDB_set_pInput(2, 2, 3);               // CT2 between V2 & V3  (etc)
    EmonLibDB_set_pInput(3, 3, 1);  
    EmonLibDB_set_pInput(4, 1, 2);  
    EmonLibDB_set_pInput(5, 2, 3);
    EmonLibDB_set_pInput(6, 3, 1);
    */
  #else
    for (byte ch=0; ch<NUM_I_CHANNELS; ch++) {
      EmonLibDB_set_pInput(ch+1, 1);
    }
  #endif
  

  /****************************************************************************
  *                                                                           *
  * Values for timing & calibration of the ADC                                *
  *                                                                           *
  *   Users in the 60 Hz world must change "cycles_per_second"                *
  *                                                                           *
  ****************************************************************************/

  // mains frequency 50Hz
  if (!USA) {
    EmonLibDB_cyclesPerSecond(50);                            // mains frequency 50Hz
  } else {
    EmonLibDB_cyclesPerSecond(60);                            // mains frequency 60Hz
  }
  EmonLibDB_minStartupCycles(10);                             // number of cycles to let ADC run before starting first actual measurement
  EmonLibDB_datalogPeriod(EEProm.period);                     // period of readings in seconds - normal value for emoncms.org
  EmonLibDB_ADCCal(reference);                                    // ADC Reference voltage, (1.024 V)


  /****************************************************************************
  *                                                                           *
  * Pulse Counting                                                            *
  *                                                                           *
  * Pulse counting on any channel is only available if the appropriate        *
  * solder link is made on the hardware, and the related "TMP" link is        *
  * broken.                                                                   *
  * The 'Analogue' input is not available if an extender card is fitted.      *
  ****************************************************************************/
 
  EmonLibDB_setPulseEnable(true);              // Enable counting on "Pulse" input
  EmonLibDB_setPulseMinPeriod(20);             // Contact bounce must not last longer than 20 ms

  EmonLibDB_setPulseEnable(2, false);           // Enable counting on "Digital" input
  // EmonLibDB_setPulseMinPeriod(2, 20, FALLING); // Contact bounce must not last longer than 20 ms, trigger on the falling edge

  EmonLibDB_setPulseEnable(3, false);          // Disable counting on "Analog" input
  // EmonLibDB_setPulseMinPeriod(3, 0, RISING);   // No contact bounce expected, trigger on the rising edge
  // EmonLibDB_setPulseCount(3, 123);             // Initialise the pulse count for this to 123 counts

  /****************************************************************************
  *                                                                           *
  * Pre-set Energy counters                                                   *
  *                                                                           *
  ****************************************************************************/

  long e0=0, e1=0, e2=0, e3=0, e4=0, e5=0;
  unsigned long p=0;
  
  recoverEValues(&e0,&e1,&e2,&e3,&e4,&e5,&p);
  EmonLibDB_setWattHour(0, e0);
  EmonLibDB_setWattHour(1, e1);
  EmonLibDB_setWattHour(2, e2);
  EmonLibDB_setWattHour(3, e3);
  EmonLibDB_setWattHour(4, e4);
  EmonLibDB_setWattHour(5, e5);
  EmonLibDB_setPulseCount(p);

#ifdef EEWL_DEBUG
  EVmem.dump_control();
  EVmem.dump_buffer();  
#endif
  EmonLibDB_Init();                                                    // Start continuous monitoring.
  emonpi.Msg = 0;
    
  // Speed up startup by making first reading 2s
  EmonLibDB_datalogPeriod(2.0);
}

void loop()             
{
  getSettings();
  
  if (EmonLibDB_Ready())   
  {
    #ifdef DEBUG
    if (emonpi.Msg==0) 
    {
      digitalWrite(LEDpin,LOW);
      EmonLibDB_datalogPeriod(EEProm.period);
      /*
      if (EmonLibCM_acPresent()) {
        Serial.println(F("AC present - Real Power calc enabled"));
      } else {
        Serial.print(F("AC missing - Apparent Power calc enabled, assuming ")); Serial.print(EEProm.assumedVrms); Serial.println(F(" V"));
      }*/
    }
    delay(5);
    #endif

    emonpi.Msg++;

    // Other options calculated by EmonLibCM
    // RMS Current:    EmonLibCM_getIrms(ch)
    // Apparent Power: EmonLibCM_getApparentPower(ch)
    // Power Factor:   EmonLibCM_getPF(ch)
    
    for (byte ch=0; ch<NUM_V_CHANNELS; ch++) {
        emonpi.V[ch] = EmonLibDB_getVrms(ch+1) * 100;
    }
    
    for (byte ch=0; ch<NUM_I_CHANNELS; ch++) {
        emonpi.P[ch] = EmonLibDB_getRealPower(ch+1);
        emonpi.E[ch] = EmonLibDB_getWattHour(ch+1);
    }
    
    emonpi.pulse = EmonLibDB_getPulseCount(1);
        
    if (EEProm.rf_on) {
      PayloadTX tmp = emonpi;

      #if RadioFormat == RFM69_LOW_POWER_LABS
        rf.sendWithRetry(5,(byte *)&tmp, sizeof(tmp));
      #else
        rf.send(0, (byte *)&tmp, sizeof(tmp));
      #endif
      
      delay(50);
    }

    if (EEProm.json_enabled) {
      // ---------------------------------------------------------------------
      // JSON Format
      // ---------------------------------------------------------------------
      Serial.print(F("{\"MSG\":")); Serial.print(emonpi.Msg);

      for (byte ch=0; ch<NUM_V_CHANNELS; ch++) {
        Serial.print(F(",\"V")); Serial.print(ch+1); Serial.print("\":"); Serial.print(emonpi.V[ch]*0.01);     
      }
      for (byte ch=0; ch<NUM_I_CHANNELS; ch++) {
        Serial.print(F(",\"P")); Serial.print(ch+1); Serial.print("\":"); Serial.print(emonpi.P[ch]);
      }
      for (byte ch=0; ch<NUM_I_CHANNELS; ch++) {
        Serial.print(F(",\"E")); Serial.print(ch+1); Serial.print("\":"); Serial.print(emonpi.E[ch]);
      }
      
      Serial.print(F(",\"pulse\":")); Serial.print(emonpi.pulse);
      Serial.println(F("}"));
      delay(60);
      
    } else {
  
      // ---------------------------------------------------------------------
      // Key:Value format, used by EmonESP & emonhub EmonHubOEMInterfacer
      // ---------------------------------------------------------------------
      Serial.print(F("MSG:")); Serial.print(emonpi.Msg);
      
      for (byte ch=0; ch<NUM_V_CHANNELS; ch++) {
        Serial.print(F(",V")); Serial.print(ch+1); Serial.print(":"); Serial.print(emonpi.V[ch]*0.01);     
      }
      for (byte ch=0; ch<NUM_I_CHANNELS; ch++) {
        Serial.print(F(",P")); Serial.print(ch+1); Serial.print(":"); Serial.print(emonpi.P[ch]);
      }
      for (byte ch=0; ch<NUM_I_CHANNELS; ch++) {
        Serial.print(F(",E")); Serial.print(ch+1); Serial.print(":"); Serial.print(emonpi.E[ch]);
      }
      
      Serial.print(F(",pulse:")); Serial.print(emonpi.pulse);
      
      if (!EEProm.showCurrents) {
        Serial.println();
        delay(40);
      } else {
        // to show voltage, current & power factor for calibration:
        for (byte ch=0; ch<NUM_I_CHANNELS; ch++) {
          Serial.print(F(",I")); Serial.print(ch+1); Serial.print(":"); Serial.print(EmonLibDB_getIrms(ch+1),3);
        }
        for (byte ch=0; ch<NUM_I_CHANNELS; ch++) {
          Serial.print(F(",pf")); Serial.print(ch+1); Serial.print(":"); Serial.print(EmonLibDB_getPF(ch+1),4);
        }
        delay(80);
      }
    }
    digitalWrite(LEDpin,HIGH); delay(50);digitalWrite(LEDpin,LOW);
    // End of print out ----------------------------------------------------
    storeEValues(emonpi.E[0],emonpi.E[1],emonpi.E[2],emonpi.E[3],emonpi.E[4],emonpi.E[5],emonpi.pulse);
  }
  wdt_reset();
  delay(20);
}


double read_reference() {
  ADC0.SAMPCTRL = 14;
  ADC0.CTRLD |= 0x0;
  VREF.ADC0REF = VREF_REFSEL_1V024_gc;
  ADC0.CTRLC = ADC_PRESC_DIV24_gc;
  ADC0.CTRLA = ADC_ENABLE_bm;
  ADC0.CTRLA |= ADC_RESSEL_12BIT_gc;

  ADC0.MUXPOS = 7;
  unsigned long sum = 0;
  for (int i=0; i<10010; i++) {
    ADC0.COMMAND = ADC_STCONV_bm;
    while (!(ADC0.INTFLAGS & ADC_RESRDY_bm));
    if (i>9) {
      sum += ADC0.RES;
    }
  }
  double mean = sum / 10000.0;
  double reference = 0.9 / (mean/4095.0);
  return reference;
}

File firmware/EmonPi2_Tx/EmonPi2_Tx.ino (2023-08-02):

/*
  emonPi2 Continuous Sampling
  using EmonLibCM https://github.com/openenergymonitor/EmonLibCM
  Authors: Robin Emley, Robert Wall, Trystan Lea
  
  -----------------------------------------
  Part of the openenergymonitor.org project
  Licence: GNU GPL V3



Change Log:
v1.0.0: First release of EmonTxV4 Continuous Monitoring Firmware (based on EmonTx v3 CM Firmware)
v1.1.0: Fixed emonEProm implementation for AVR-DB & new serial config implementation
v1.2.0: LowPowerLabs radio format, with option to switch to JeeLib classic or native.
v1.3.0: Read and calibrate reference voltage at startup
v1.4.0: Option to output serial data as JSON (Brian Orpin)
v1.5.0: emonEProm fixed pulse count data type issue
v1.5.1: default node id set to 17, swap nodeid DIP, zero all 6 energy values
v1.5.2: emonEProm fixed EEWL overlap
v1.5.3: Slightly slower sample rate to improve zero power performance
        temperature sensing disabled if no temperature sensors detected at startup
v1.5.4: Fix emonEProm EEWL overlap properly
v1.5.5: RFM69_LPL library update use setPins
v1.5.6: uses version 3.0.8 of EmonLibCM avrdb branch
        reduces interference caused by DS18B20 temperature sensing
v1.5.7: Fix disabling of temperature sensing at startup if none detected

*/
#define Serial Serial3

#define RFM69_JEELIB_CLASSIC 1
#define RFM69_JEELIB_NATIVE 2
#define RFM69_LOW_POWER_LABS 3

#define RadioFormat RFM69_LOW_POWER_LABS

const char *firmware_version = {"1.5.7\n\r"};
/*

emonhub.conf node decoder (nodeid is 17 when switch is off, 18 when switch is on)
See: https://github.com/openenergymonitor/emonhub/blob/emon-pi/configuration.md
copy the following into emonhub.conf:

[[17]]
  nodename = emonPi2_17
  [[[rx]]]
    names = MSG, Vrms, P1, P2, P3, P4, P5, P6, E1, E2, E3, E4, E5, E6, T1, T2, T3, pulse
    datacodes = L,h,h,h,h,h,h,h,l,l,l,l,l,l,h,h,h,L
    scales = 1,0.01,1,1,1,1,1,1,1,1,1,1,0.01,0.01,0.01,1
    units = n,V,W,W,W,W,W,W,Wh,Wh,Wh,Wh,Wh,Wh,C,C,C,p

*/
// Comment/Uncomment as applicable
#define DEBUG                                              // Debug level print out
#define EMONTX4

// #define EEWL_DEBUG

#define OFF HIGH
#define ON LOW

#define RFM69CW

#include <Arduino.h>
#include <avr/wdt.h>

#if RadioFormat == RFM69_LOW_POWER_LABS
  #include "RFM69_LPL.h"
#else
  #include "RFM69_JeeLib.h"                                        // Minimal radio library that supports both original JeeLib format and later native format
#endif

// EEWL_START = 102, Start EEPROM wear leveling section after config section which takes up first 99 bytes, a few bytes of padding here
// EEWL_BLOCKS = 14, 14 x 29 byte blocks = 406 bytes. EEWL_END = 102+406 = 508 a few bytes short of 512 byte limit
// EEWL is only updated if values change by more than 200Wh, this means for a typical house consuming ~4000kWh/year
// 20,000 writes per channel to EEPROM, there's a 100,000 write lifetime for any individual EEPROM byte.
// With a circular buffer of 14 blocks, this extends the lifetime from 5 years to 70 years.
// IMPORTANT! If adding to config section change EEWL_START and check EEWL_END Implications.

#include <emonEProm.h>                                     // OEM EEPROM library
#include <emonLibCM.h>                                     // OEM Continuous Monitoring library

// Include EmonTxV4_config.ino in the same directory for settings functions & data

RFM69 rf;

typedef struct {
    unsigned long Msg;
    int Vrms,P1,P2,P3,P4,P5,P6; 
    long E1,E2,E3,E4,E5,E6; 
    int T1,T2,T3;
    unsigned long pulse;
} PayloadTX;                                                  // create a data packet for the RFM
PayloadTX emontx;
static void showString (PGM_P s);
 
#define MAX_TEMPS 3                                        // The maximum number of temperature sensors
 
//---------------------------- emonTx Settings - Stored in EEPROM and shared with config.ino ------------------------------------------------
#define DEFAULT_ICAL 60.06                                // 25A / 333mV output = 75.075
#define DEFAULT_LEAD 3.2

struct {
  byte RF_freq = RF69_433MHZ;                              // Frequency of radio module can be RFM_433MHZ, RFM_868MHZ or RFM_915MHZ. 
  byte networkGroup = 210;                                 // wireless network group, must be the same as emonBase / emonPi and emonGLCD. OEM default is 210
  byte nodeID = 17;                                        // node ID for this emonTx.
  byte rf_on = 1;                                          // RF - 0 = no RF, 1 = RF on.
  byte rfPower = 25;                                       // 7 = -10.5 dBm, 25 = +7 dBm for RFM12B; 0 = -18 dBm, 31 = +13 dBm for RFM69CW. Default = 25 (+7 dBm)
  float vCal  = 807.86;                                    // (6 x 10000) / 75 = 800.0
  float assumedVrms = 240.0;                               // Assumed Vrms when no a.c. is detected
  float lineFreq = 50;                                     // Line Frequency = 50 Hz

  float i1Cal =  300.30;
  float i1Lead = DEFAULT_LEAD;
  float i2Cal =  150.15;
  float i2Lead = DEFAULT_LEAD;
  float i3Cal =  150.15;
  float i3Lead = DEFAULT_LEAD;
  float i4Cal =  DEFAULT_ICAL;                                     
  float i4Lead = DEFAULT_LEAD;                                      
  float i5Cal =  DEFAULT_ICAL;
  float i5Lead = DEFAULT_LEAD;
  float i6Cal =  DEFAULT_ICAL;
  float i6Lead = DEFAULT_LEAD;
  
  float period = 9.8;                                      // datalogging period - should be fractionally less than the PHPFINA database period in emonCMS
  bool  pulse_enable = true;                               // pulse counting
  int   pulse_period = 100;                                // pulse min period - 0 = no de-bounce
  bool  temp_enable = true;                                // if no temperature sensors are detected at startup this is over ridden and temperature sensing is disabled
  DeviceAddress allAddresses[MAX_TEMPS];                   // sensor address data
  bool  showCurrents = false;                              // Print to serial voltage, current & p.f. values
  bool  json_enabled = false;                              // JSON Enabled - false = key,Value pair, true = JSON, default = false: Key,Value pair.  
} EEProm;

uint16_t eepromSig = 0x0016;                               // oemEProm signature - see oemEProm Library documentation for details.
 
#ifdef EEWL_DEBUG
  extern EEWL EVmem;
#endif

DeviceAddress allAddresses[MAX_TEMPS];                     // Array to receive temperature sensor addresses
/*   Example - how to define temperature sensors, prevents an automatic search
DeviceAddress allAddresses[] = {       
    {0x28, 0x81, 0x43, 0x31, 0x7, 0x0, 0xFF, 0xD9}, 
    {0x28, 0x8D, 0xA5, 0xC7, 0x5, 0x0, 0x0, 0xD5},         // Use the actual addresses, as many as required
    {0x28, 0xC9, 0x58, 0x32, 0x7, 0x0, 0x0, 0x89}          // up to a maximum of 6    
};
*/
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

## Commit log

2022-06-17 emonPi2 schematic and board file
    [emonPi_v2.0.0-beta.brd, emonPi_v2.0.0-beta.sch]
2022-06-26 rfm69pi designs
    [rfm69pi2_rj11_ct.brd, rfm69pi2_rj11_ct.sch, rfm69pi2_terminal_blocks.brd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]
2022-07-12 emonpi2 fascia
    [fascias.brd, fascias.sch]
2022-07-12 updated board file
    [emonPi_v2.0.0-beta.brd]
2022-07-12 fix push switch
    [emonPi_v2.0.0-beta.brd, emonPi_v2.0.0-beta.sch]
2023-04-04 emonPi v2 redesigned to use AVR128DB48++
    [emonPi_v2.0.0-beta.brd, emonPi_v2.0.0-beta.sch, emonPi_v2.0.0.brd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]
2023-04-16 fix print currents and PF
    [EmonPi2_Tx.ino]
2023-04-17 updated fascia
    [fascias_v2.0.0.brd]
2023-04-17 fascias and CT expansion board
    [emonPi_v2.0.0_CT_ext.brd, emonPi_v2.0.0_CT_ext.sch, fascias_v2.0.0.brd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]
2023-04-17 fascia text
    [#fascias_v2.0.0.dxf, fascias_v2.0.0.brd]
2023-05-03 add fascia export and CAM file
    [#fascias_v2.0.0.dxf, fascias_v2.0.0-2mm.dxf]
2023-05-04 component label positions
    [emonPi_v2.0.1.brd]
2023-05-19 print radio status to serial
2023-07-19 latest fascia design
    [fascias_v2.0.1.zig1.brd, fascias_v2.0.1.zig1.sch]
2023-07-26 fascia designs
    [buttom_plate_2mm_BLACK_acrylic_plain.brd, fascias_v2.0.0.sch, fascias_v2.0.1.zig1.sch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]
2023-09-06 dxf export of top plate
    [top_plate_A_2mm_clear_acrylic_screenprint_dxf_export.brd, top_plate_A_2mm_clear_acrylic_screenprint_dxf_export.dxf]
2023-09-07 longer sd card slot to support pi zero
    [fascias_v2.1.0_dxf_prepare_r2.brd]
2023-09-07 archive rev1 fascias
    [#fascias_v2.0.0-2mm.dxf, fascias_v2.0.0-2mm.dxf, fascias_v2.0.0.brd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]
2023-09-07 update fascias
    [back.brd, frontA.brd]
2023-10-06 add dimentions
    [back.brd, frontA.brd]
2023-10-09 vector files fascias
    [back.brd, back.dxf, bottom.brd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]
2023-11-07 fascia amendments 7th Nov
    [back.brd, top.brd]
2023-11-07 revised back
    [back.brd]
2023-11-07 updated dxf
    [back.dxf, bottom.dxf, front.dxf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]
2023-11-07 updated dimension
    [back.brd]
2023-11-30 update other sensors
2023-12-21 voltage sensor pinout
2024-01-02 current only example
2024-04-26 update print
2024-05-26 current only
2024-05-26 3-phase 4-wire and n,american systems
2025-03-03 doc: added notes for the emonVs power supply/voltage sensor
2026-10-11 docs: fix broken links in install guide
    Point the emonVs link at the emonVs installation section of the guide
    (voltage_sensors.md does not exist in this repo) and fix the numbered
    section anchors.

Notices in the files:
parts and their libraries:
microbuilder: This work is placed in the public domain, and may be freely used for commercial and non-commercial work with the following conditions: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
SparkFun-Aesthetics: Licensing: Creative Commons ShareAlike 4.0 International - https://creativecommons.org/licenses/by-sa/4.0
